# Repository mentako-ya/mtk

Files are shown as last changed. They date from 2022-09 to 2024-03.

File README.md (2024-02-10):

# mtk

homebrew keyboard with thumb operated trackball & rotary encoder.

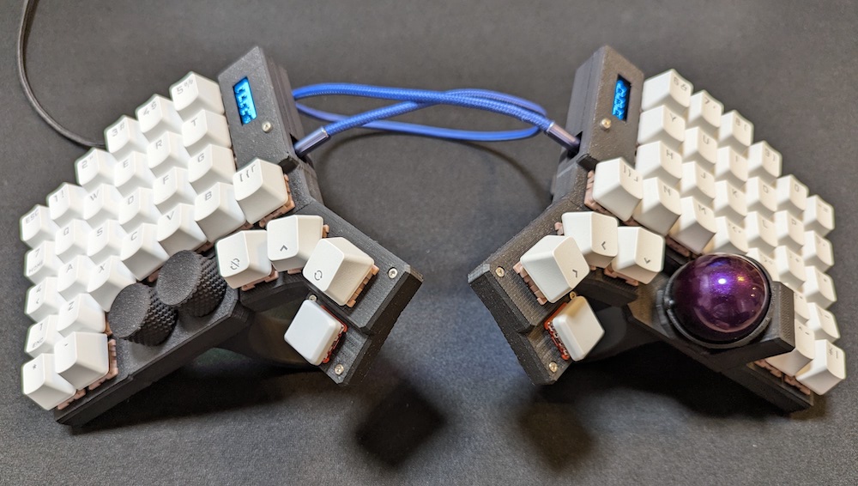
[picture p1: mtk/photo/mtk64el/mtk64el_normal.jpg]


mtk64el 作例
- キーキャップ:CORSAIR PBT DOUBLE-SHOT 交換用カラーキーキャップセット - 日本語108キー, Arctic White - CH-9911040-JP
- トラックボール：ぺリックス PERIPRO-303 GP 34 mm
- TRRSケーブル：https://shop.dailycraft.jp/products/trrs_cable_50_gloss
- USB Type-cケーブル：https://amzn.asia/d/h8pfZIJ

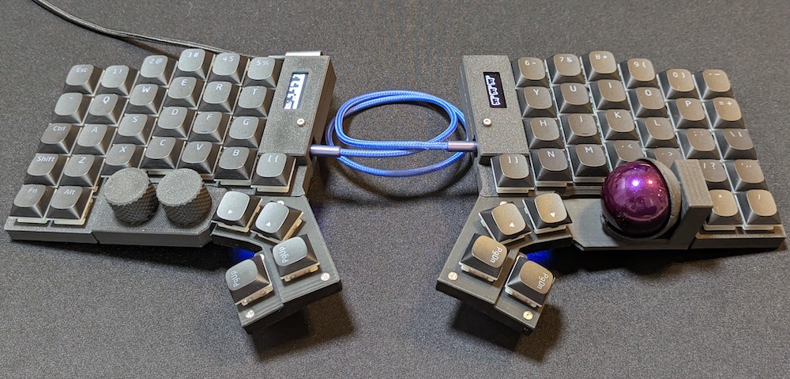
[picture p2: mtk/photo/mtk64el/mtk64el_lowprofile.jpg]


mtk64el ロープロファイル 作例



mtk64el ロープロファイル(Lofree + Chock V1) 作例
- キースイッチ(メイン部分):[LOFREE x KAILH Full POM Low Profile Switches](https://amzn.asia/d/74pwfkn)
- キーキャップ(メイン部分):[XVX ロープロファイル PBT キーキャップ](https://amzn.asia/d/7V1A6T4)
- キースイッチ(親指部分):[Kailhロープロファイルスイッチ - Pink](https://amzn.asia/d/bSlNIMm)
- キーキャップ(親指部分):[Chocfox CFX keycap](https://talpkeyboard.net/items/638b518dcc223746ee14eae8)



mtk64el Lofree Full POM ロープロファイルスイッチ取り付け例
- [LOFREE x KAILH Full POM Low Profile Switches](https://amzn.asia/d/74pwfkn)



mtk64el MX互換キースイッチ取り付け用トッププレート



mtk64el アンダーグロー

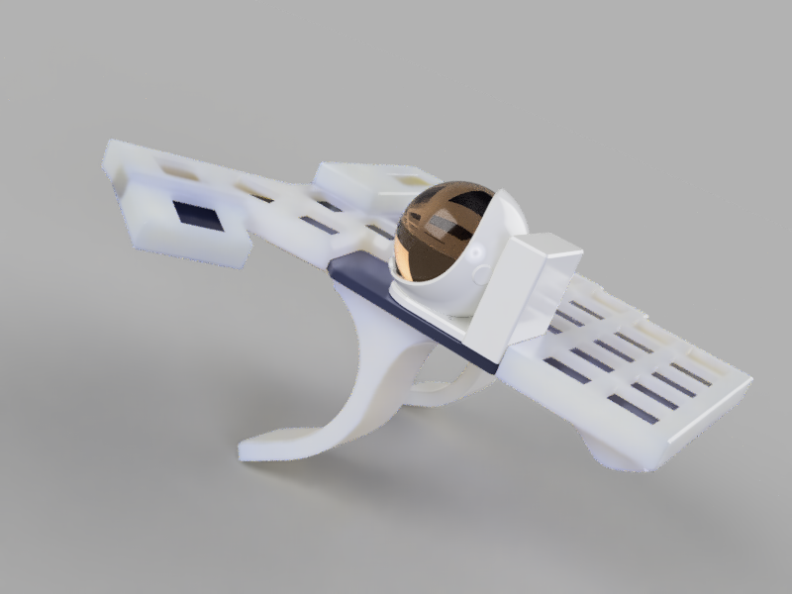
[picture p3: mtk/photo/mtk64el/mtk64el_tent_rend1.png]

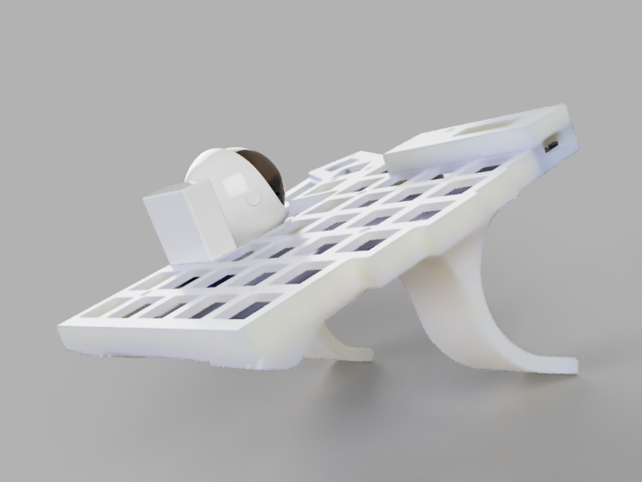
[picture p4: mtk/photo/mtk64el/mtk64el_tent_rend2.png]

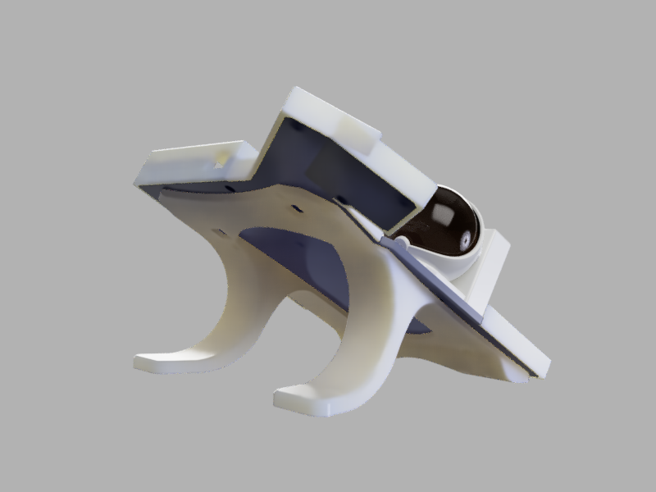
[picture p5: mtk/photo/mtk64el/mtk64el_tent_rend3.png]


[rev3ケースプリント用3Dデータ](mtk/design/mtk64elt_STL/rev3)　/ テントスタンド[3Dデータ右](mtk/design/mtk64elt_STL/rev3/mtk64el_rev3_tent_RH.stl)　/ [3Dデータ左](mtk/design/mtk64elt_STL/rev3/mtk64el_rev3_tent_LH.stl) 

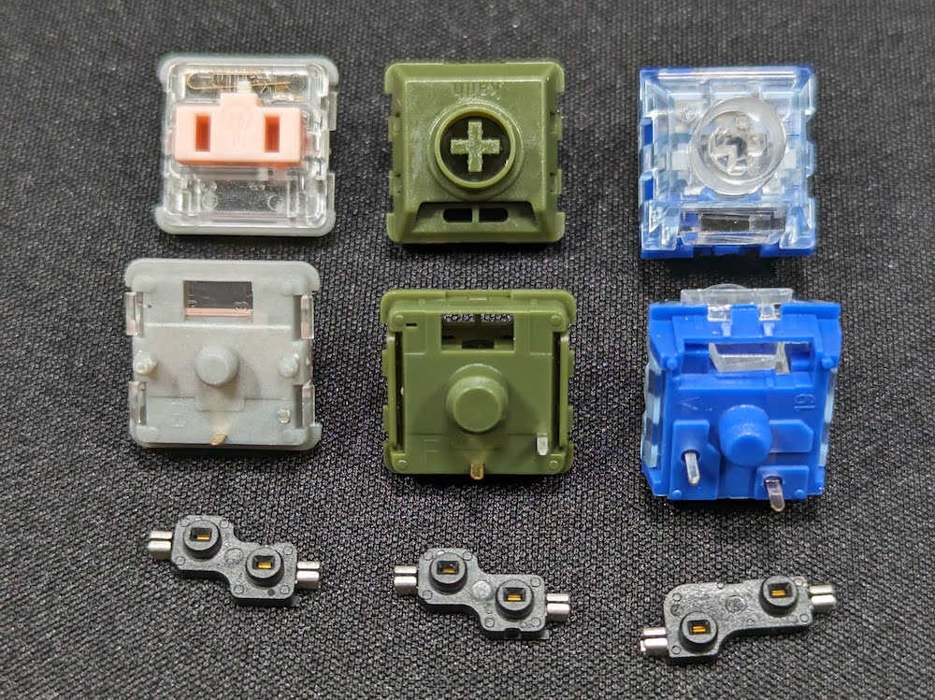
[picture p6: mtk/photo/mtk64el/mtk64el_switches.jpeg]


Chock V1スイッチ / Lofree Shadowスイッチ / MX互換スイッチ

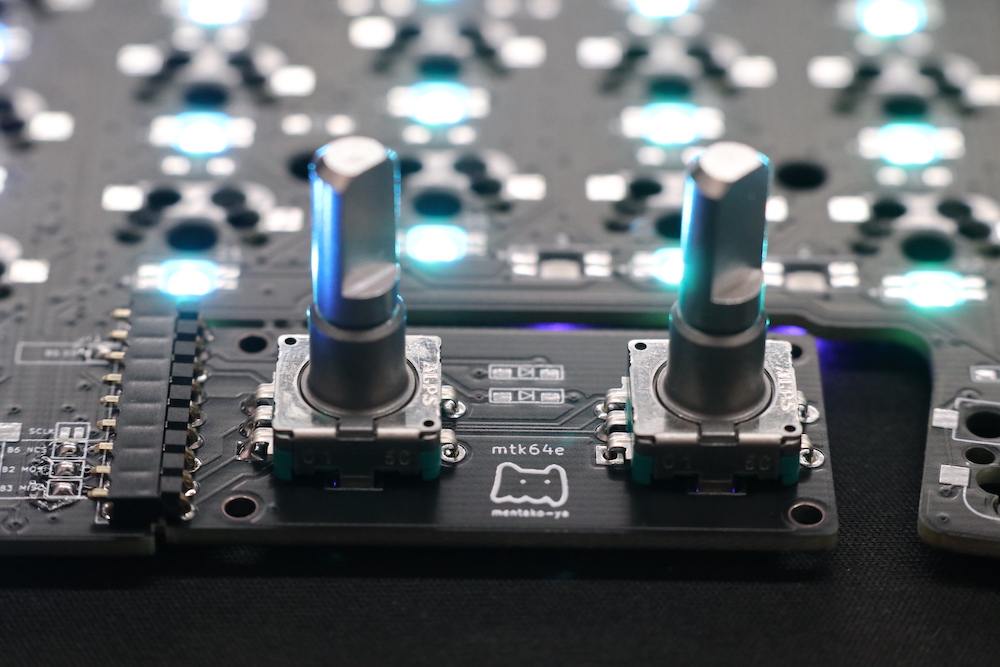
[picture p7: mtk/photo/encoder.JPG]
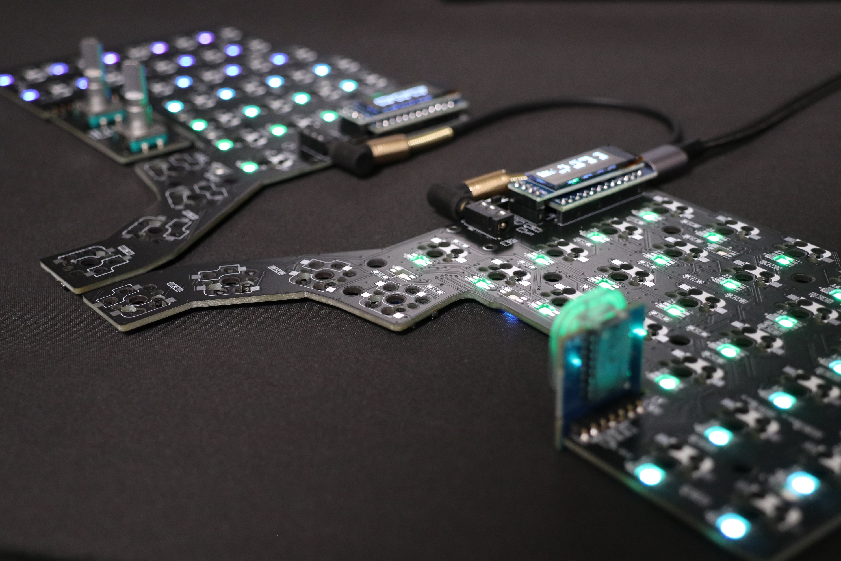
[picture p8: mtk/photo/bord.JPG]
　
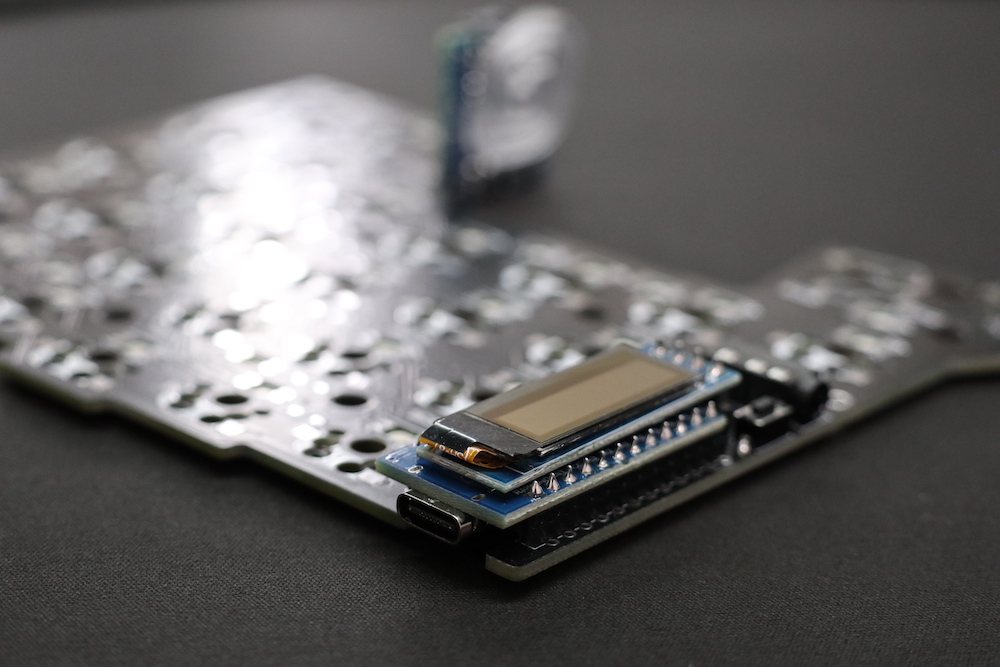
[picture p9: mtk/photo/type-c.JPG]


[insnote](https://insnote.net)様にてmtk64eのレビューを掲載いただきました。　https://insnote.net/homebrewkeyboard-mtk64e_review/

mtk64eの使用感、カスタマイズなどご紹介いただいております。導入をご検討されている方はぜひご一読ください。

## remap対応 ファームウェア  

!!! Remap https://remap-keys.app のアップデートにより、従来のファームウェア（qmk_firmware 0.16ベース）を使用したキーボードを接続すると、エラーメッセージが表示されマッピング変更ができません。
https://remap-keys.app をご利用の場合、qmk_firmware 0.22ベースのファームウェアをご使用ください。

### qmk_firmware 0.22ベース ファームウェア https://remap-keys.app をご使用ください

#### PMW3389センサー用
<details>

- [mtk_mtk64e_PMW3389_AutoMouseLayer_via.0.22.hex](https://raw.githubusercontent.com/mentako-ya/mtk/main/mtk/mtk_mtk64e_PMW3389_AutoMouseLayer_via.0.22.hex)
 rev3基板 PMW3389センサー　左ロータリーエンコーダー、右ボール用、自動マウスレイヤー切替

- [mtk_mtk64e_PMW3389_AutoMouseLayer_via_leftball.0.22.hex](https://raw.githubusercontent.com/mentako-ya/mtk/main/mtk/mtk_mtk64e_PMW3389_AutoMouseLayer_via_leftball.0.22.hex)
 rev3基板 PMW3389センサー　右ロータリーエンコーダー、左ボール用、自動マウスレイヤー切替

- [mtk_mtk64e_PMW3389_AutoMouseLayer_via_db.0.22.hex](https://raw.githubusercontent.com/mentako-ya/mtk/main/mtk/mtk_mtk64e_PMW3389_AutoMouseLayer_via_db.0.22.hex)
 rev3基板 PMW3389センサー　左右ボール用、自動マウスレイヤー切替

- [mtk_mtk64e_PMW3389_AutoMouseLayer_via_db.0.22.hex](https://raw.githubusercontent.com/mentako-ya/mtk/main/mtk/mtk_mtk64e_PMW3389_AutoMouseLayer_via_db.0.22.hex)
 rev3基板 PMW3389センサー　左右ボール用（Master側ポインター、Slabe側スクロール）、自動マウスレイヤー切替

- [mtk_mtk64e_PMW3389_AutoMouseLayer_via_db.0.22.hex](https://raw.githubusercontent.com/mentako-ya/mtk/main/mtk/mtk_mtk64e_PMW3389_AutoMouseLayer_via_db_noscrl.0.22.hex)
 rev3基板 PMW3389センサー　左右ボール用（両側ポインター）、自動マウスレイヤー切替

</details>

#### PMW3360センサー用
<details>

- [mtk_mtk64e_PMW3360_AutoMouseLayer_via.0.22.hex](https://raw.githubusercontent.com/mentako-ya/mtk/main/mtk/mtk_mtk64e_PMW3360_AutoMouseLayer_via.0.22.hex)
 rev2基板 PMW3360センサー　左ロータリーエンコーダー、右ボール用、自動マウスレイヤー切替

- [mtk_mtk64e_PMW3360_AutoMouseLayer_via_leftball.0.22.hex](https://raw.githubusercontent.com/mentako-ya/mtk/main/mtk/mtk_mtk64e_PMW3360_AutoMouseLayer_via_leftball.0.22.hex)
 rev2基板 PMW3360センサー　右ロータリーエンコーダー、左ボール用、自動マウスレイヤー切替

- [mtk_mtk64e_PMW3360_AutoMouseLayer_via_db.0.22.hex](https://raw.githubusercontent.com/mentako-ya/mtk/main/mtk/mtk_mtk64e_PMW3360_AutoMouseLayer_via_db.0.22.hex)
 rev2基板 PMW3360センサー　左右ボール用、自動マウスレイヤー切替

- [mtk_mtk64e_PMW3360_AutoMouseLayer_via_db.0.22.hex](https://raw.githubusercontent.com/mentako-ya/mtk/main/mtk/mtk_mtk64e_PMW3360_AutoMouseLayer_via_db.0.22.hex)
 rev2基板 PMW3360センサー　左右ボール用（Master側ポインター、Slabe側スクロール）、自動マウスレイヤー切替

- [mtk_mtk64e_PMW3360_AutoMouseLayer_via_db.0.22.hex](https://raw.githubusercontent.com/mentako-ya/mtk/main/mtk/mtk_mtk64e_PMW3360_AutoMouseLayer_via_db_noscrl.0.22.hex)
 rev2基板 PMW3360センサー　左右ボール用（両側ポインター）、自動マウスレイヤー切替

</details>

!!! qmk_firmware 0.16ベースのファームウェアでRemapをご使用の場合、旧バージョンのRemap https://qmk018.remap-keys.app をご利用ください。

### qmk_firmware 0.16ベース ファームウェア https://qmk018.remap-keys.app を使用
<details>

- [mtk_mtk64_via.hex](https://raw.githubusercontent.com/mentako-ya/mtk/main/mtk/mtk_mtk64_via.hex)
 rev1基板　右ボール/左ボール/左右ボール用
   
- [mtk_mtk64e_via.hex](https://raw.githubusercontent.com/mentako-ya/mtk/main/mtk/mtk_mtk64e_via.hex)
 rev2基板 PMW3360センサー　左ロータリーエンコーダー、右ボール用

- [mtk_mtk64e_left_ball_via.hex](https://raw.githubusercontent.com/mentako-ya/mtk/main/mtk/mtk_mtk64e_left_ball_via.hex)
 rev2基板 PMW3360センサー　右ロータリーエンコーダー、左ボール用
   
- [mtk_mtk64e_AutoMouseLayer_via.hex](https://raw.githubusercontent.com/mentako-ya/mtk/main/mtk/mtk_mtk64e_AutoMouseLayer_via.hex)
 rev2基板 PMW3360センサー　左ロータリーエンコーダー、右ボール用、自動マウスレイヤー切替

- [mtk_mtk64e_AutoMouseLayer_via_db.hex](https://raw.githubusercontent.com/mentako-ya/mtk/main/mtk/mtk_mtk64e_AutoMouseLayer_via_db.hex)
 rev2基板 PMW3360センサー　左右ボール用（Master側ポインター、Slabe側スクロール）、自動マウスレイヤー切替

- [mtk_mtk64e_AutoMouseLayer_via_db_noscrl.hex](https://raw.githubusercontent.com/mentako-ya/mtk/main/mtk/mtk_mtk64e_AutoMouseLayer_via_db_noscrl.hex)
 rev2基板 PMW3360センサー　左右ボール用（両側ポインター）、自動マウスレイヤー切替
   
- [mtk_mtk64e_AutoMouseLayer_via_leftball.hex](https://raw.githubusercontent.com/mentako-ya/mtk/main/mtk/mtk_mtk64e_AutoMouseLayer_via_leftball.hex)
 rev2基板　右ロータリーエンコーダー、左ボール用、自動マウスレイヤー切替

- [mtk_mtk64e_PMW3389_AutoMouseLayer_via.hex](https://raw.githubusercontent.com/mentako-ya/mtk/main/mtk/mtk_mtk64e_PMW3389_AutoMouseLayer_via.hex)
 rev3基板 PMW3389センサー　左ロータリーエンコーダー、右ボール用、自動マウスレイヤー切替

</details>

## remap用 via.json

- [mtk64_rb_via.json](https://raw.githubusercontent.com/mentako-ya/mtk/main/mtk/mtk64_rb_via.json)     rev1 mtk64　右ボール用 
    
- [mtk64_db_via.json](https://raw.githubusercontent.com/mentako-ya/mtk/main/mtk/mtk64_db_via.json)  rev1 mtk64　左右ボール用 
    
- [mtk64e_via.json](https://raw.githubusercontent.com/mentako-ya/mtk/main/mtk/mtk64e_via.json)      rev2,rev3 mtk64e　ロータリーエンコーダー＆ボール、左右ボール用

## ご自身でファームウェアをカスタマイズ、ビルドする場合 

   [via firmware ビルドガイド](qmk_firmware/keyboards/mtk/)

## 更新情報

<details>

### mtk64el rev3ケースデータを追加しました

   [rev3ケースデータ](mtk/design/mtk64elt_STL/rev3)

### mtk64el になりました
   親指末端のキーを手前斜め下、親指側面で押下する位置に配置しました。

   親指部分にCherryMX互換キーを使用する場合でも、末端のキーのみロープロファイルで使用する設計です。
   
   全キーロープロファイル化が可能になりました。
  
   ロープロファイルキーはGateron Low Profile 2.0 (KS-33) を使用します。（Kailh chock v1は使用できません）

   トラックボールケースの形状を変更してボールが落ちにくくなりました。
   
   LEDはアンダーグローのみになりました。

   ファームウェアはmtk64eと共通です。

### ファームウェアが　qmk_firmware 0.22 ベースになりました
   ファームウェアを　qmk_firmware 0.22 ベースに更新しました。
   
   Remap [https://remap-keys.app] のアップデートに対応しました。

### トラックボールセンサーをPMW3389に更新しました
   トラックボールセンサーをより高性能なPMW3389DM-T3QUに更新しました。
   
   [PMW3360DM-T2QUとPMW3389DM-T3QUの比較](https://www.pixart.com/products-comparison/7/Optical_Mouse_Sensor)
   
   ファームウェアはPMW3389センサー用になります。
   
   従来のPMW3360センサーを使用したキーボードをご使用の場合、ファームウェアはPMW3360センサー用をご使用ください。
   
### 右ロータリーエンコーダー、左ボール用、自動マウスレイヤー切替有効　ファームウェアを追加しました

   [mtk_mtk64e_AutoMouseLayer_via_leftball.hex](https://raw.githubusercontent.com/mentako-ya/mtk/main/mtk/mtk_mtk64e_AutoMouseLayer_via_leftball.hex) rev2基板用　右ロータリーエンコーダー、左ボール用、自動マウスレイヤー切替

   ソースコード : https://github.com/mentako-ya/mtk/tree/mtk64e_leftball

### ファームウェアを再ビルドしました
   [mtk_mtk64e_AutoMouseLayer_via.hex](https://raw.githubusercontent.com/mentako-ya/mtk/main/mtk/mtk_mtk64e_AutoMouseLayer_via.hex) rev2基板用　左ロータリーエンコーダー、右ボール用、自動マウスレイヤー切替

   [mtk_mtk64e_AutoMouseLayer_via_db.hex](https://raw.githubusercontent.com/mentako-ya/mtk/main/mtk/mtk_mtk64e_AutoMouseLayer_via_db.hex) rev2基板用　左右ボール用（Master側ポインター、Slabe側スクロール）、自動マウスレイヤー切替

   [mtk_mtk64e_AutoMouseLayer_via_db_noscrl.hex](https://raw.githubusercontent.com/mentako-ya/mtk/main/mtk/mtk_mtk64e_AutoMouseLayer_via_db_noscrl.hex) rev2基板用　左右ボール用（両側ポインター）、自動マウスレイヤー切替
   
   qmk_firmwareのバージョン不整合により、キーボード接続時に初期化処理が正しく動作しない場合があったため、qmk_firmware 0.16.3 で再ビルドしました。
   再ビルドによりレイヤー３のカスタムキーコードが変わりました。ファームウェア更新した場合、キーマップをリセットするか、新しいキーコードとの対応を確認してキーマッピングを修正してください。
　
### オーディオ制御とシステム制御キーを有効化しました
   [mtk_mtk64e_AutoMouseLayer_via.hex](https://raw.githubusercontent.com/mentako-ya/mtk/main/mtk/mtk_mtk64e_AutoMouseLayer_via.hex)
   
   ご自身でファームウェアをビルドする場合、[rules.mk](https://github.com/mentako-ya/mtk/blob/cd9f4ba413dade68378f4804782a1528e7ef739e/qmk_firmware/keyboards/mtk/mtk64e/rules.mk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)の
   ```EXTRAKEY_ENABLE = no        # Audio control and System control```
   をyesに修正してください。
   
   ファームウェアのサイズが上限に近いため、有効化している機能の組み合わせによっては、ファイル容量オーバーによりビルドできない場合があります。

### 左右ボール用ファームウェアを追加しました。
   [mtk_mtk64e_AutoMouseLayer_via_db.hex](https://raw.githubusercontent.com/mentako-ya/mtk/main/mtk/mtk_mtk64e_AutoMouseLayer_via_db.hex) rev2基板用　左右ボール用（Master側ポインター、Slabe側スクロール）、自動マウスレイヤー切替
   [mtk_mtk64e_AutoMouseLayer_via_db_noscrl.hex](https://raw.githubusercontent.com/mentako-ya/mtk/main/mtk/mtk_mtk64e_AutoMouseLayer_via_db_noscrl.hex) rev2基板用　左右ボール用（両側ポインター）、自動マウスレイヤー切替

### 意図せずマウスレイヤー２が解除されてしまうバグに対応しました。
自動でマウスレイヤーに切り替わっている間に手動でレイヤー２に切り替えると、一定時間経過後にレイヤー２が解除されるバグに対応しました。

### エンコーダーの解像度を調整しました。
[エンコーダーの仕様](https://tech.alpsalpine.com/j/products/detail/EC11E18244AU/#ancFig3)に合わせて、'ENCODER_RESOLUTION 4 → 2' に調整しました。

### 自動マウスレイヤーから元のレイヤーに戻る時間を0.1秒単位で調整可能にしました。
調整用カスタムキーコード
- KC_TO_RESET_INC　0x5DB2
- KC_TO_RESET_DEC　0x5DB3

### トラックボール操作時に自動でマウスレイヤー2に切り替わる対応を追加しました。
[takashicompanyさんの実装](https://zenn.dev/takashicompany/articles/69b87160cda4b9)を参考にしています。

[mtk_mtk64e_AutoMouseLayer_via.hex](https://raw.githubusercontent.com/mentako-ya/mtk/main/mtk/mtk_mtk64e_AutoMouseLayer_via.hex)

※容量の都合でこちらのファームウェアはLEDエフェクトを省略しています。（LEDのOn/Off、色と明るさ調整は可能、点滅やグラデーションは不可）
LEDエフェクトが必要な場合、従来のファームウェアをご利用ください。

### 通電直後のエンコーダー誤作動対応を追加しました。

### バックプレートが透明アクリル製になりました。
バックプレート固定用の低頭6角穴付きボルトの付け外しには[T5サイズのレンチ](https://amzn.asia/d/b8Xeegc)を使用します。

### メインの基板が黒色になりました。

### 親指のロープロファイルキーの向きを内向きに変更しました。
[MCC-profile POM Choc keycap](https://shop.yushakobo.jp/products/3694)のような、シリンドリカル（円柱状に凹んでいる形状）のキーを使用できます。

[MBK Choc Low-Profile Keycaps](https://shop.yushakobo.jp/products/mbk-choc-low-profile-keycaps)のような、スフィリカル（お椀状に凹んでいる形状）のキーでは手前側の角が親指に当たって痛くなってしまう方におすすめです。（mtk64elでは使用できません）
</details>

## キーボードの接続

まず、動作確認のために右左の各キーボードを単体でPCに接続し、キー入力が可能であること、OLEDにキーボードの情報が表示されることを確認してください。（OLEDは一定時間操作しないと消灯します）

USB Type-c ケーブルは充電器や携帯電話などの製品に付属のケーブルは使用できません。USB2.0/USB3.0の表記のあるデータ通信用のケーブルを使用してください。
PCからキーボードとして認識されない場合、USBケーブルがデータ通信用ではない、USBケーブルがケースと干渉してプロマイクロにしっかり刺さっていないなどの可能性があります。

根元の形状が太いUSBケーブルや特殊な形状のUSBケーブルは、ケースと干渉する場合があります。
作例は[こちら](https://amzn.asia/d/gQuaIi1)のUSBケーブルを使用しています。

USB2.0のケーブルを使用してType-c端子にケーブルをきちんと差し込んだたうえで、接続時にキー入力できない場合やOLEDに何も表示されない場合、ロゴが表示されていてキー情報（数値やコード）が表示されない場合は、OLEDの斜め下にあるリセットボタン（ボルトの頭）をプッシュするか、キーボードを接続し直してください。

USBケーブルに問題がなく、動作しない場合は、プロマイクロのコンスルーが抜けかけている、回路がショートしていて起動できない（LEDの取り付け方向間違いでこの状態になることが多いです）などのハードウェアの問題か、ファームウェアが消えているなどのソフトウェアの問題が考えられます。

USB接続時にプロマイクロ裏側の赤いランプが点灯しているか、USB端子の隙間から確認してください。
赤いLEDが点灯していない場合、点灯してもすぐ消えてしまう場合ば、ハードウェアの問題です。

左右単体で動作確認できたら、TRSケーブルで左右を接続し、どちらか一方のUSB端子をPCに接続してください。

左右を繋ぐと動作しない場合、TRSケーブルが奥まできちんと刺さっていないか、TRSケーブルの断線、接触不良が考えられます。
TRSケーブルは、ケーブル付け根が本体のケースの中まで入り込む設計です。ねじ込むようにしてしっかり奥まで差し込んでください。

ジャックの付け根が太いケーブルやL字のケーブルはケースに干渉するため、根元の細いケーブルを使用するか、ケース側を加工する必要があります。
作例は[こちら](https://shop.dailycraft.jp/products/trrs_cable_50_gloss)のTRRSケーブルを使用しています。

スリープからの復帰の際にキーボードが動作しなくなる場合、PC側のUSB省電力設定やUSBセレクティブサスペンドをOFFにするか、OLED斜め下のリセットボタン押下、USBケーブルの再接続で復帰してください。

## キーマップ変更

キーマップの変更はChromeブラウザを使用して、https://remap-keys.app　で変更します。

（旧バージョンのqmk_firmware 0.16ベースのファームウエアをご使用の場合、https://qmk018.remap-keys.app　で変更します。）

下記に本キーボードを使用する際に最低限必要な手順を記載します。

remapの一般的な使用方法はサリチル酸さんの記事などをご参照ください。

　https://salicylic-acid3.hatenablog.com/entry/remap-manual

1. [START REMAP FOR YOUR KEYBORD]　をクリック

<img width="500" src="mtk/remap_img/remap_1.png">

2. [+ KEYBORD]をクリック

<img width="500" src="mtk/remap_img/remap_2.png">

3. [mtk64] か。[mtk64e]を選択して接続.

<img width="250" src="mtk/remap_img/remap_3.png">

4. Jsonファイルのアップロードを求められるので、下記からレイアウトに合わせたjsonファイルをダウンロードして使用する

<img width="500" src="mtk/remap_img/remap_4.png">

- mtk64 右ボール用 [mtk64_rb_via.json](https://raw.githubusercontent.com/mentako-ya/mtk/main/mtk/mtk64_rb_via.json)
- mtk64 左右ボール用 [mtk64_db_via.json](https://raw.githubusercontent.com/mentako-ya/mtk/main/mtk/mtk64_db_via.json)
- mtk64e ロータリーエンコーダー＆ボール、両側ボール用 [mtk64e_via.json](https://raw.githubusercontent.com/mentako-ya/mtk/main/mtk/mtk64e_via.json)

5. キーマップの変更 / キーマップの書き込み（右上Flashボタン） /　変更したキーマップの保存　/　キーマップのPDFダウンロード　などが可能

右ボール　キーマップサンプル

- via keyleyout(right ball) [mtk64_rb_via.json](https://raw.githubusercontent.com/mentako-ya/mtk/main/mtk/mtk64_rb_via.json)
- sample keymap cheetsheet(right ball) [mtk64_rb_keymap_cheatsheet.pdf](mtk/mtk64_rb_keymap_cheatsheet.pdf)

<img width="1186" alt="remap_key_leyout" src="mtk/remap_img/mtk64_rb_keymap.png">

左右ボール　キーマップサンプル

- via keyleyout(double ball) [mtk64_db_via.json](https://raw.githubusercontent.com/mentako-ya/mtk/main/mtk/mtk64_db_via.json)
- sample keymap cheetsheet(double ball) [mtk64_db_keymap_cheatsheet.pdf](mtk/mtk64_db_keymap_cheatsheet.pdf)

<img width="1186" alt="remap_key_leyout_double_ball" src="mtk/remap_img/mtk64_db_keymap.png">

mtk64e ロータリーエンコーダー＆ボール、左右ボール　キーマップサンプル

- via keyleyout(rotary encoder) [mtk64e_via.json](https://raw.githubusercontent.com/mentako-ya/mtk/main/mtk/mtk64e_via.json)
- sample keymap cheetsheet(rotary encoder) [mtk64e_keymap_cheatsheet.pdf](mtk/mtk64e_keymap_cheatsheet.pdf)
- sample keymap cheetsheet(rotary encoder) [mtk64e_AutoMouseLayer_keymap_cheatsheet.pdf](mtk/mtk64e_AutoMouseLayer_keymap_cheatsheet.pdf)

<img width="1186" alt="remap_key_leyout_rotary_encoder" src="mtk/remap_img/mtk64e_keymap.png">

※ 製品出荷時点でキーボードに設定済みのマッピングは、ファームウェアのデフォルトキーマッピングとは一部異なる場合があります。

キーマップのリセットや、キーボードの初期化を行うと、キーマップはファームウェアのデフォルトキーマップにリセットされます。

キーマップ変更やリセットを行う前に、初期のマッピングの状態でマップの保存をお勧めします。

## ファームウェア更新
[Pro Micro Web Updater](https://sekigon-gonnoc.github.io/promicro-web-updater/index.html) を使用してファームウェアを更新できます。

出荷時に書き込まれているファームウェアは[mtk_mtk64e_AutoMouseLayer_via.hex](https://raw.githubusercontent.com/mentako-ya/mtk/main/mtk/mtk_mtk64e_AutoMouseLayer_via.hex)になります。　

[Pro Micro Web Updater](https://sekigon-gonnoc.github.io/promicro-web-updater/index.html) にアクセスし、事前にダウンロードしたファームウェアをアップロードします。

キーボードの左右どちらか一方をUSB接続し、画面上の[flash]ボタンを押下します。

シリアルポートへの接続要求のウインドウが表示されるので、OLED斜め下のリセットスイッチ（ボルトの頭）を２回連続でクリックします。

シリアルポートの一覧に「Pro Micro 5v」が表示されるので、選択して接続ボタンを押下します。

## 基本的な使用方法

本キーボードは、レイヤー０〜3の４種類のキーマップを切り替えて使用します。

レイヤーの切り替えは左手親指キーのHOLD（シフトキーのように押したままにすること）に割り当てられており、左端からLayer(1),Layer(2),Layer(3)が設定されています。

- レイヤー０:通常のアルファベット入力
- レイヤー１:Shiftキー押下相当（大文字入力や記号入力）
- レイヤー２:右手のキーがマウスのボタンに切り替わる
- レイヤー３:トラックボールがスクロールモードに切り替わる、キースイッチはLEDの調整、トラックボールの速度、スクロールの速度調整

自動マウスレイヤー切替に対応したファームウェアでは、トラックボールを一定距離動かすと自動的にレイヤー2に切り替わり、マウスボタンクリックが可能になります。
デフォルトでは１秒間何も操作しないとレイヤー0に戻ります。
自動マウスレイヤー切替機能がOnの場合、OLED３行目が反転表示されます。
（レイヤー３左側のキーボード最下段左から２番目のキーで自動切替機能On／Off）

## レイヤー３トラックボール設定のコード値
レイヤー３にマッピングされているキーのうち、トラックボールの設定を行うキーは、のカスタムコードで設定します。
Remapでは User0 ~（旧バージョンRemapでは16進数）で設定します。

コード値については下記の表を参照してください。

- RemapのUserキー:旧バージョンRemapの16進コード:keymap.cのカスタムコード　

### レイヤー３トラックボール設定のコード値　mtk64　（mtk_mtk64_via.hex/mtk_mtk64e_via.hex）
- User 0:0x5DA5:KBC_RST    トラックボール設定リセット
- User 1:0x5DA6:KBC_SAVE   トラックボール設定保存（次回接続時にトラックボール設定が保存された値になっている）
- User 2:0x5DA7:CPI_I100   トラックボールのカーソル速度 +100
- User 3:0x5DA8:CPI_D100   トラックボールのカーソル速度 -100
- User 4:0x5DA9:CPI_I1K    トラックボールのカーソル速度  +1000
- User 5:0x5DAA:CPI_D1K    トラックボールのカーソル速度 -1000
- User 6:0x5DAB:SCRL_TO    トラックボールのスクロールモードOn/Off
- User 7:0x5DAC:SCRL_MO    トラックボールのスクロールモードOn
- User 8:0x5DAD:SCRL_DVI   トラックボールのスクロール速度を下げる
- User 9:0x5DAE:SCRL_DVD   トラックボールのスクロール速度を上げる

### レイヤー３トラックボール設定のコード値　mtk64e自動マウスレイヤー　（mtk_mtk64e_AutoMouseLayer_via.0.22.hex）
- User 0:0x5DB1:KBC_RST    トラックボール設定リセット
- User 1:0x5DB2:KBC_SAVE   トラックボール設定保存（次回接続時にトラックボール設定が保存された値になっている）
- User 2:0x5DB3:CPI_I100   トラックボールのカーソル速度 +100
- User 3:0x5DB4:CPI_D100   トラックボールのカーソル速度 -100
- User 4:0x5DB5:CPI_I1K    トラックボールのカーソル速度 +1000
- User 5:0x5DB6:CPI_D1K    トラックボールのカーソル速度 -1000
- User 6:0x5DB7:SCRL_TO    トラックボールのスクロールモードOn/Off
- User 7:0x5DB8:SCRL_MO    トラックボールのスクロールモードOn
- User 8:0x5DB9:SCRL_DVI   トラックボールのスクロール速度を下げる
- User 9:0x5DBA:SCRL_DVD   トラックボールのスクロール速度を上げる

### レイヤー３自動マウスレイヤー切替設定のコード値　mtk64e自動マウスレイヤー　（mtk_mtk64e_AutoMouseLayer_via.0.22.hex）
- User10:0x5DBB:KC_TG_CLICKABLE     自動マウスレイヤー切替On/Off (有効時にOLEDを反転表示）
- User11:0x5DBC:KC_TO_CLICKABLE_INC 自動マウスレイヤー切替距離 +
- User12:0x5DBD:KC_TO_CLICKABLE_DEC 自動マウスレイヤー切替距離 -
- User13:0x5DBE:KC_TO_RESET_INC     自動マウスレイヤーから元のレイヤーに戻る時間 + 0.1秒
- User14:0x5DBF:KC_TO_RESET_DEC.    自動マウスレイヤーから元のレイヤーに戻る時間 - 0.1秒
 
## 左右トラックボール構成の動作

[mtk_mtk64e_AutoMouseLayer_via_db.hex](https://raw.githubusercontent.com/mentako-ya/mtk/main/mtk/mtk_mtk64e_AutoMouseLayer_via_db.hex) を使用するとUSBケーブルを挿した側（Master)がポインター操作、反対側（Slave）がスクロール操作（上下左右）になります。
レイヤー３に切り替えた際に左右のモードが入れ替わります。

[mtk_mtk64e_AutoMouseLayer_via_db_noscrl.hex](https://raw.githubusercontent.com/mentako-ya/mtk/main/mtk/mtk_mtk64e_AutoMouseLayer_via_db_noscrl.hex) を使用するとMaster側Slave側ともポインター操作になります。
レイヤー３に切り替えた際に左右ともスクロールになります。

## トラックボールのお手入れ
ボールとボールケースの白い支持球はこまめに掃除していただくと、滑りがよくなり快適に使用できます。

白い支持球周辺に埃が溜まりますので、時々ボールを外してメガネ拭きなどで掃除してください。
ボールの滑りが悪いと、狙ったところをカーソルが飛び越してしまい、使いづらくなります。

ボールに[シリコンスプレー](https://amzn.asia/d/2fwdtvX)を少量塗布して、ティッシュ、メガネ拭き、[キムワイプ](https://www.amazon.co.jp/dp/B001EHI9XI)などで軽く拭っていただくと、滑りが良くなり、操作性が向上します。

定期的にシリコンを塗布する必要がありますが、シリコンスプレーは1本あれば数年使用できます。

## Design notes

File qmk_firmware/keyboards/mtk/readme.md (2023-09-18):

## How to build

1. [mtk](https://github.com/mentako-ya/mtk/)をチェックアウトします.

    ※ チェックアウト先 `~/git` は適宜変更

    ```console
    $ cd ~/git
    $ git clone https://github.com/mentako-ya/mtk.git mtk
    ```

2. [qmk/qmk_firmware](https://github.com/qmk/qmk_firmware/) より qmk_firmware ver.0.22.3 をチェックアウトします.

    ```console
    $ cd ~/git
    $ git clone https://github.com/qmk/qmk_firmware.git --depth 1 --recurse-submodules --shallow-submodules -b 0.22.3 qmk_firmware
    ```

3. `qmk_firmware/keyboards/` フォルダに　`/mtk/qmk_firmware/keyboards/mtk` のシンボリックリンクを作成し、`qmk_firmware/keyboards/mtk` とします。

    ```console
    $ ls
    mtk/ qmk_firmware/

    $ cd qmk_firmware/keyboards
    $ ln -s ../../mtk/qmk_firmware/keyboards/mtk mtk
    $ ls mtk/
    drivers/  mtk/  lib/  readme.md
    ```

4. ファームウェアをビルドしてし、キーボードに書き込み(flash)します.

   - 右ボール左エンコーダーの場合
   
        [qmk_firmware/keyboards/mtk/mtk64e/keymaps/via/config.h](qmk_firmware/keyboards/mtk/mtk64e/keymaps/via/config.h) を確認します。
        ```c++
        // #### 自動マウスレイヤー切替有効化 ####
        #define AUTO_MOUSE_LAYER_ENABLE

        // #### エンコーダー設定 ####
        // 左エンコーダー有効 左ボール無効（デフォルト）
        #define ENCODER_LEFT_ENABLE
        // 右エンコーダー有効 右ボール無効
        //#define ENCODER_RIGHT_ENABEL

        // #### 両側ボール設定 ####
        //#undef ENCODER_ENABLE
        // slave側トラックボールをスクロール操作に使用する場合（デフォルト）
        //#define SLAVE_SCRL_DISABLE 0
        // slave側トラックボールをポインター操作に使用する場合
        //#define SLAVE_SCRL_DISABLE 1
        ```

     - make を使用する場合.
        ```console
        $ cd ~/git/qmk_firmware
        $ make -j8 SKIP_GIT=yes mtk/mtk64e:via:flash
        ```

     - qmk を使用する場合.　　　
        ```console
        $ cd ~/git/qmk_firmware
        $ qmk clean -a
        $ qmk flash -kb mtk/mtk64e -km via
        Ψ Compiling keymap with gmake --jobs=1 mtk/mtk64e:via:flash
        ~
        Waiting for USB serial port - reset your controller now (Ctrl+C to cancel)..........
        ```
        ビルドが成功するとUSBシリアルポートの接続待ちになるので、接続したキーボードのリセットスッチを２回押下して書き込みを開始します。
        一方の書き込みが完了したら、再度flashを実行して反対のキーボードにも書き込みます。

   - 左ボール右エンコーダーの場合
   
        [qmk_firmware/keyboards/mtk/mtk64e/keymaps/via/config.h](qmk_firmware/keyboards/mtk/mtk64e/keymaps/via/config.h) を編集します。
        ```c++
        // #### 自動マウスレイヤー切替有効化 ####
        #define AUTO_MOUSE_LAYER_ENABLE

        // #### エンコーダー設定 ####
        // 左エンコーダー有効 左ボール無効（デフォルト）
        //#define ENCODER_LEFT_ENABLE
        // 右エンコーダー有効 右ボール無効
        #define ENCODER_RIGHT_ENABEL

        // #### 両側ボール設定 ####
        // #undef ENCODER_ENABLE
        // slave側トラックボールをスクロール操作に使用する場合（デフォルト）
        // #define SLAVE_SCRL_DISABLE 0
        // slave側トラックボールをポインター操作に使用する場合
        //#define SLAVE_SCRL_DISABLE 1
        ```
        右ボール左エンコーダーの場合と同じくビルドしてし、キーボードに書き込み(flash)します。
    
   - 両側ボールの場合
   
        [qmk_firmware/keyboards/mtk/mtk64e/keymaps/via/config.h](qmk_firmware/keyboards/mtk/mtk64e/keymaps/via/config.h) を編集します。
        ```c++
        // #### 自動マウスレイヤー切替有効化 ####
        #define AUTO_MOUSE_LAYER_ENABLE

        // #### エンコーダー設定 ####
        // 左エンコーダー有効 左ボール無効（デフォルト）
        #define ENCODER_LEFT_ENABLE
        // 右エンコーダー有効 右ボール無効
        //#define ENCODER_RIGHT_ENABEL

        // #### 両側ボール設定 ####
        #undef ENCODER_ENABLE
        // slave側トラックボールをスクロール操作に使用する場合（デフォルト）
        #define SLAVE_SCRL_DISABLE 0
        // slave側トラックボールをポインター操作に使用する場合
        //#define SLAVE_SCRL_DISABLE 1
        ```
        右ボール左エンコーダーの場合と同じくビルドしてし、キーボードに書き込み(flash)します。

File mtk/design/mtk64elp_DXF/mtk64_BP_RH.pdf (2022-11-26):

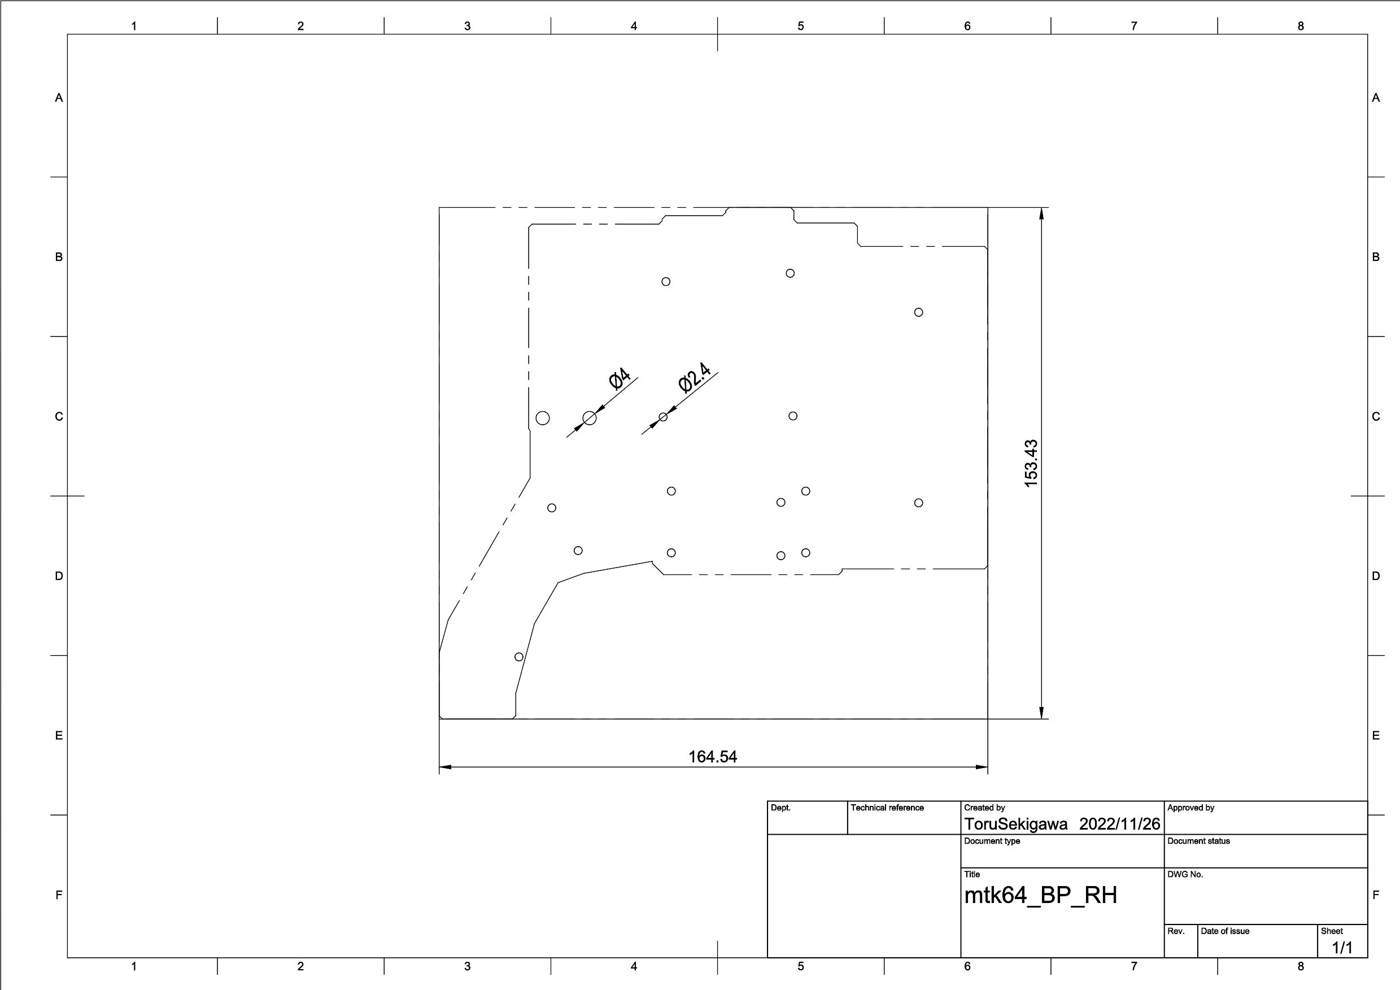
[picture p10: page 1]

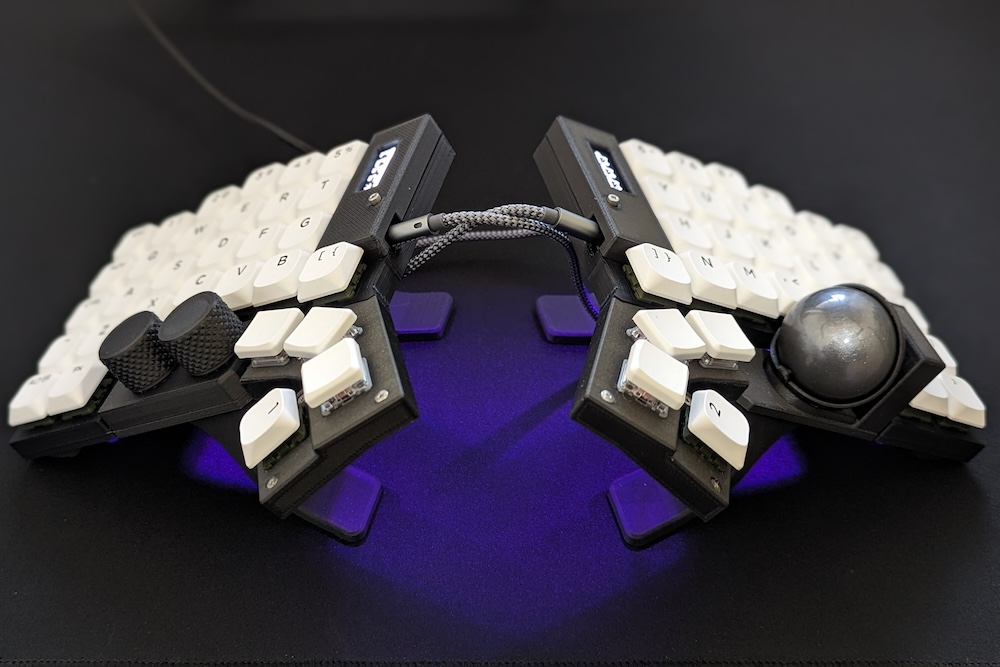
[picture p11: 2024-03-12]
mtk/photo/mtk64el/mtk64el_low_tent.jpg

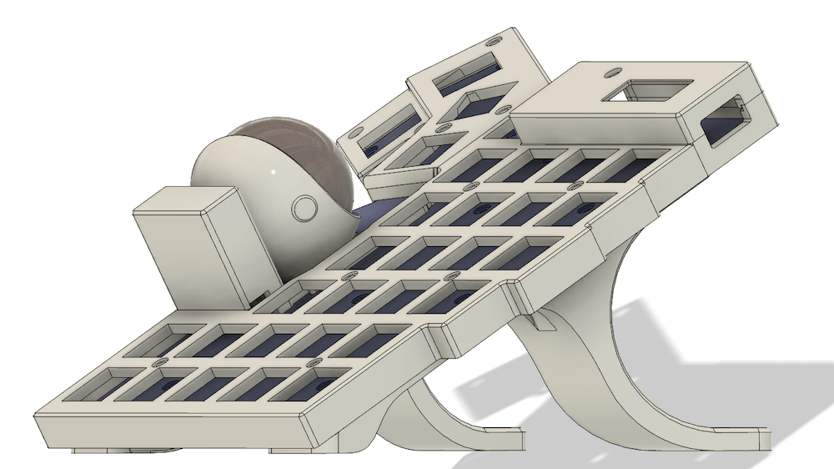
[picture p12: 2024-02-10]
mtk/photo/mtk64el/mtk64el_lowpro_case.png

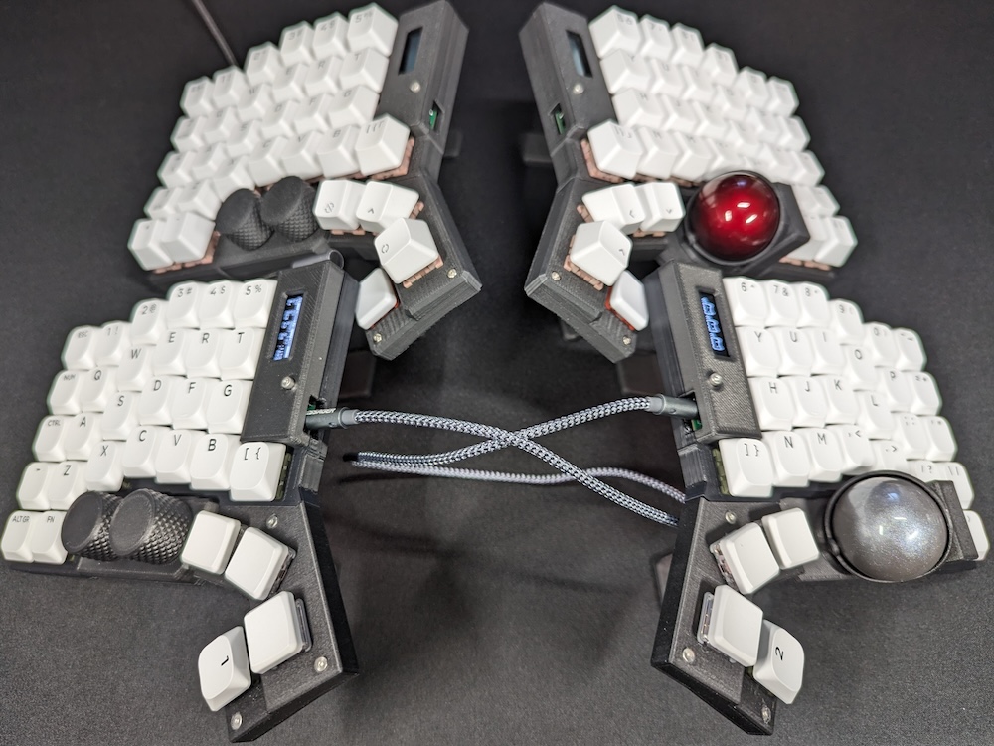
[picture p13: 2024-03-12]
mtk/photo/mtk64el/mtk64el_low_high.jpg

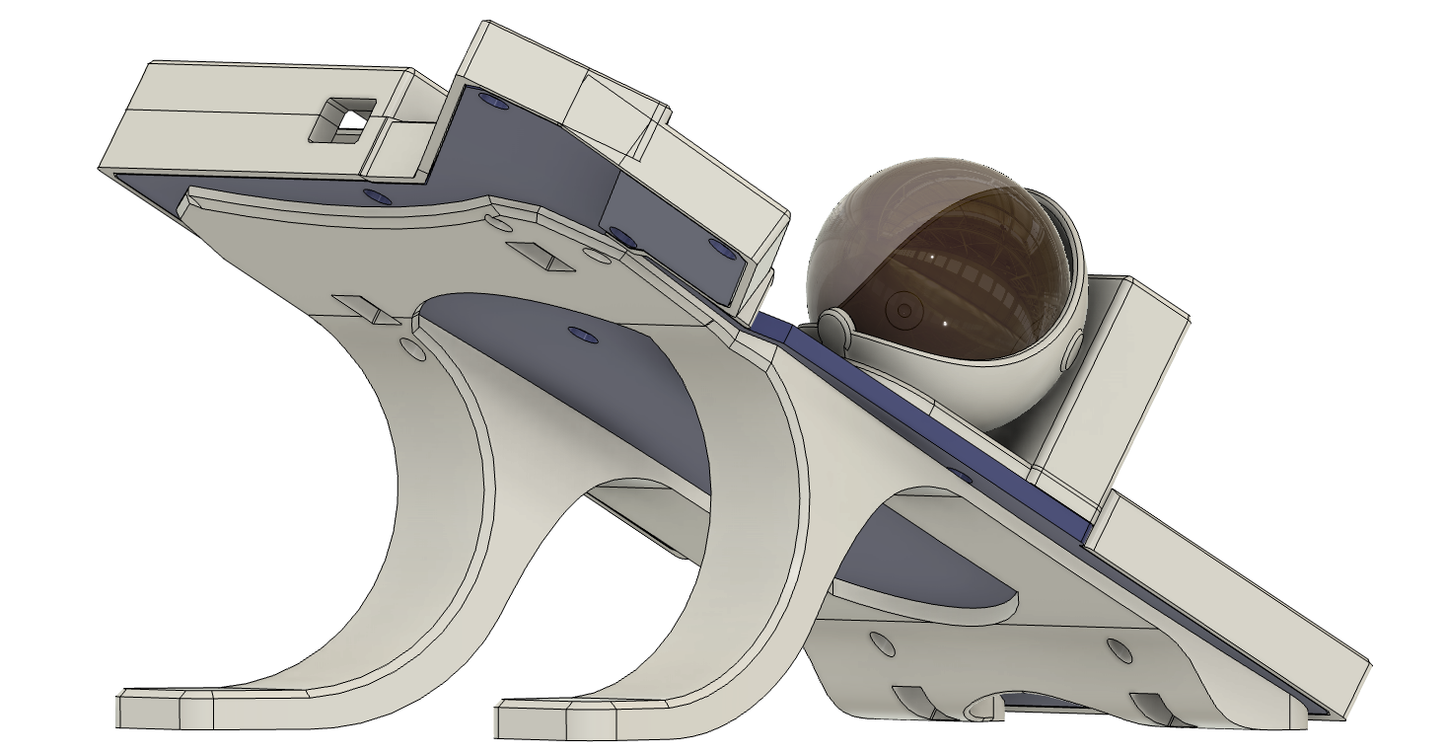
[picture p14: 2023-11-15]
mtk/photo/mtk64el/mtk64el_tent.png

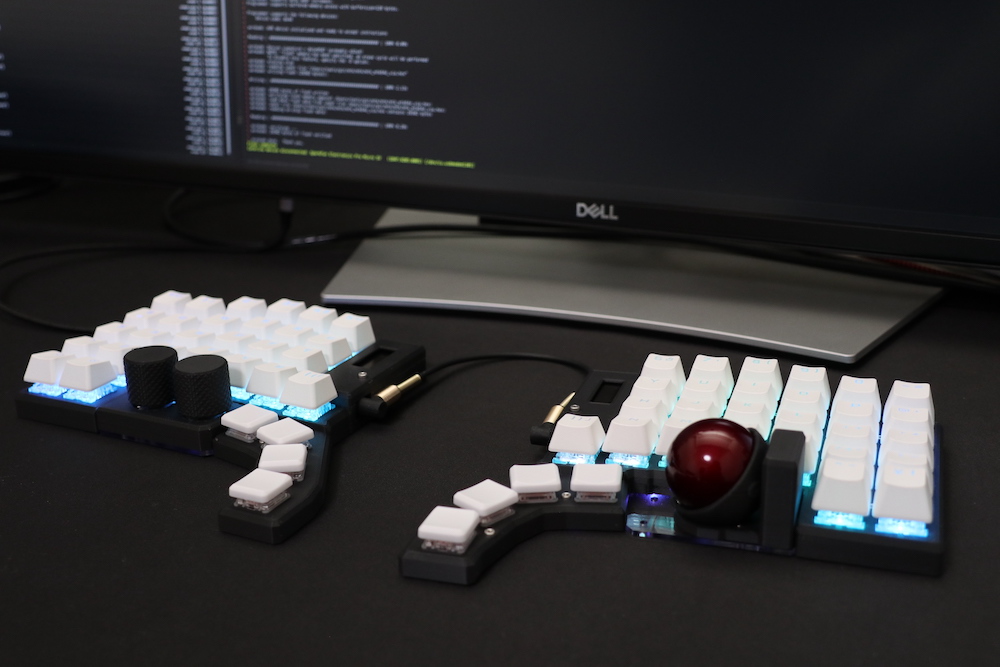
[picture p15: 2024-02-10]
mtk/photo/mtk64e.JPG

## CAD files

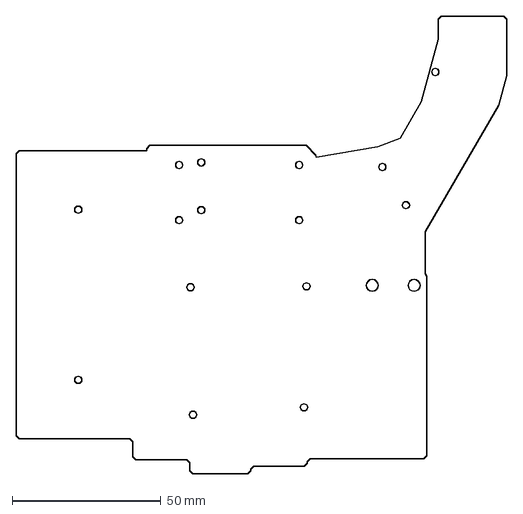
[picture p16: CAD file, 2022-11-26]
mtk/design/mtk64elp_DXF/mtk64_BP_RH.dxf
164.5 x 153.4 mm

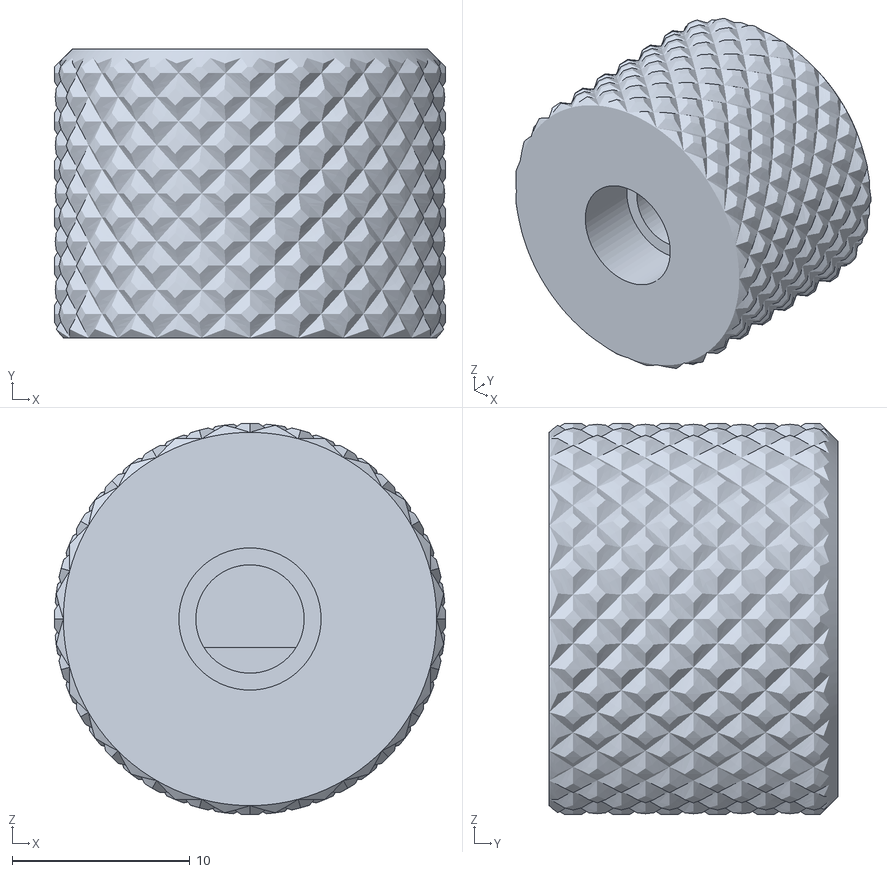
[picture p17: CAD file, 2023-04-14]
mtk/design/mtk64elp_STL/EC11N1524402_knob_v7.stl
22.0 x 16.2 x 22.0

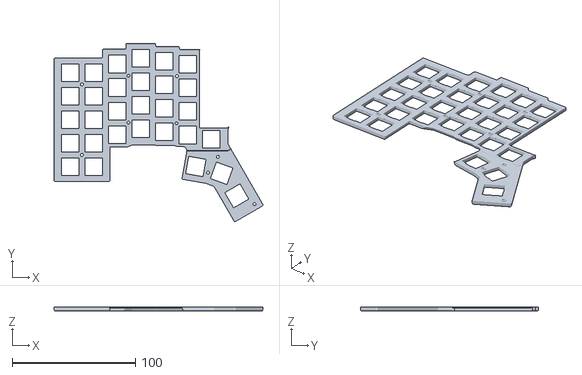
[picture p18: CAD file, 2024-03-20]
mtk/design/mtk64elt_STL/rev3/mtk64el_rev3_top_RH.stl
169.3 x 144.3 x 2.90

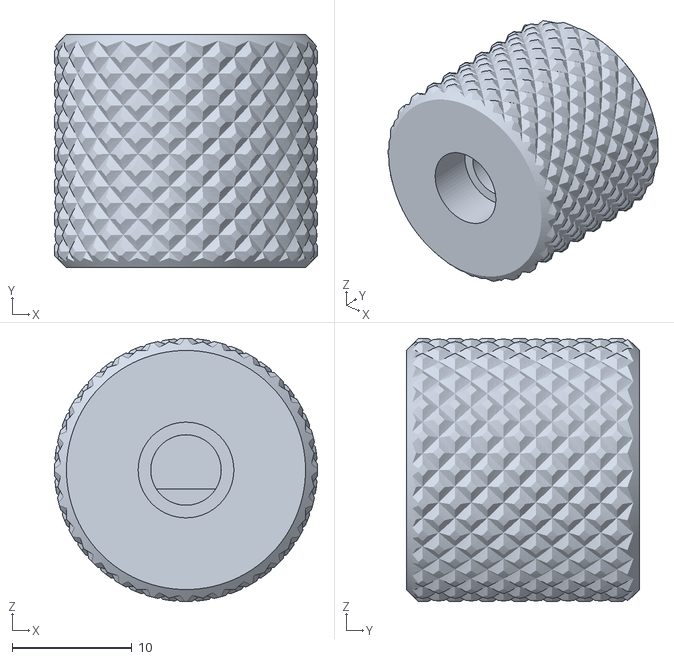
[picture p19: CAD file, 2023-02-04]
mtk/design/mtk64elp_STL/EC11E18244AU_Knob v8.stl
22.0 x 19.5 x 22.0

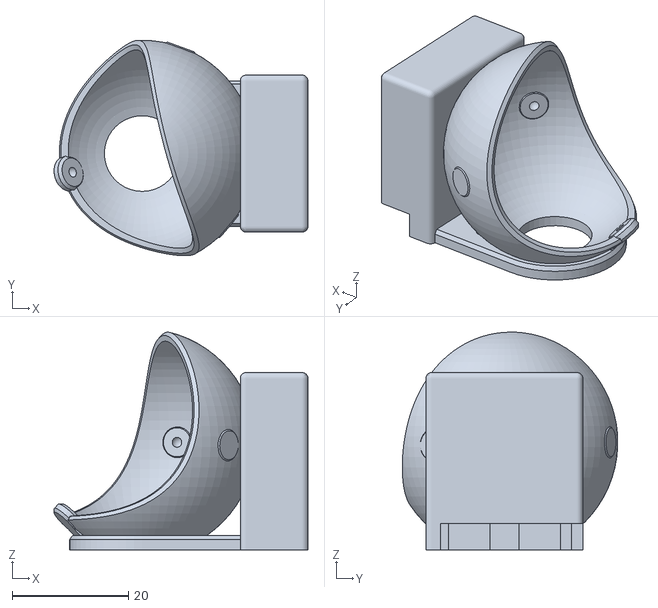
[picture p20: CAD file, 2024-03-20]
mtk/design/mtk64elt_STL/rev3/mtk64el_rev3_trackBallCase_RH.stl
43.7 x 37.1 x 37.5

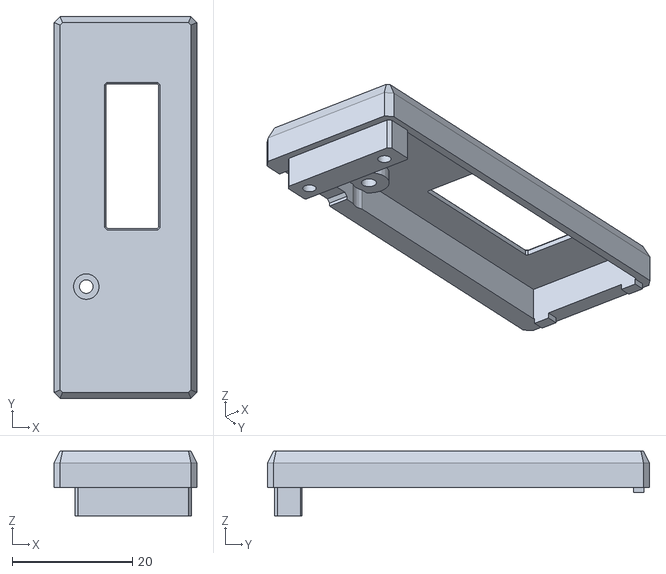
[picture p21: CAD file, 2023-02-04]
mtk/design/mtk64elp_STL/mtk64_PMCase_RH_rev4 v16.stl
23.8 x 63.5 x 10.8

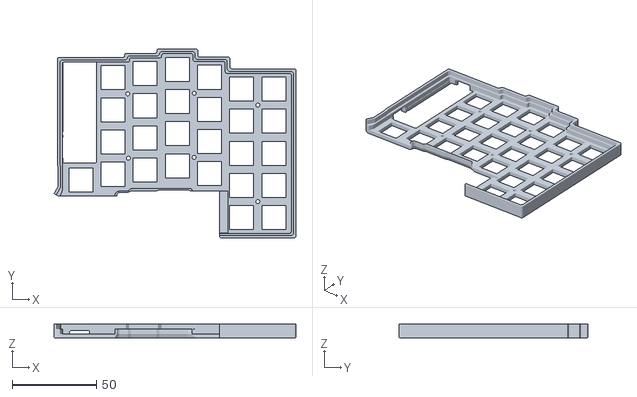
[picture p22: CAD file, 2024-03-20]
mtk/design/mtk64elt_STL/rev3/mtk64el_rev3_body_LH.stl
143.3 x 111.9 x 8.50

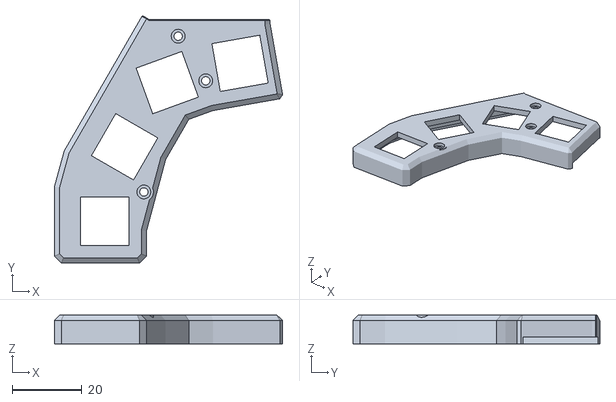
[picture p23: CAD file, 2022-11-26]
mtk/design/mtk64elp_STL/mtk64_TunmbLow_RH_rev4 v0.stl
65.5 x 70.9 x 8.20

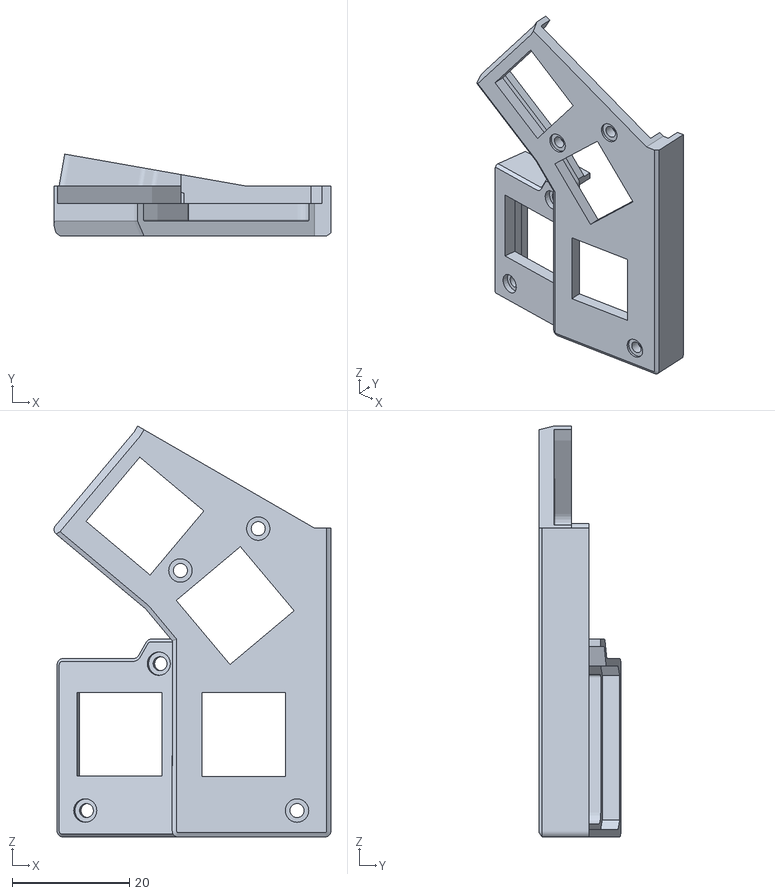
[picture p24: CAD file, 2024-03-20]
mtk/design/mtk64elt_STL/rev3/mtk64el_rev3_thumb_LH.stl
47.2 x 13.9 x 70.0

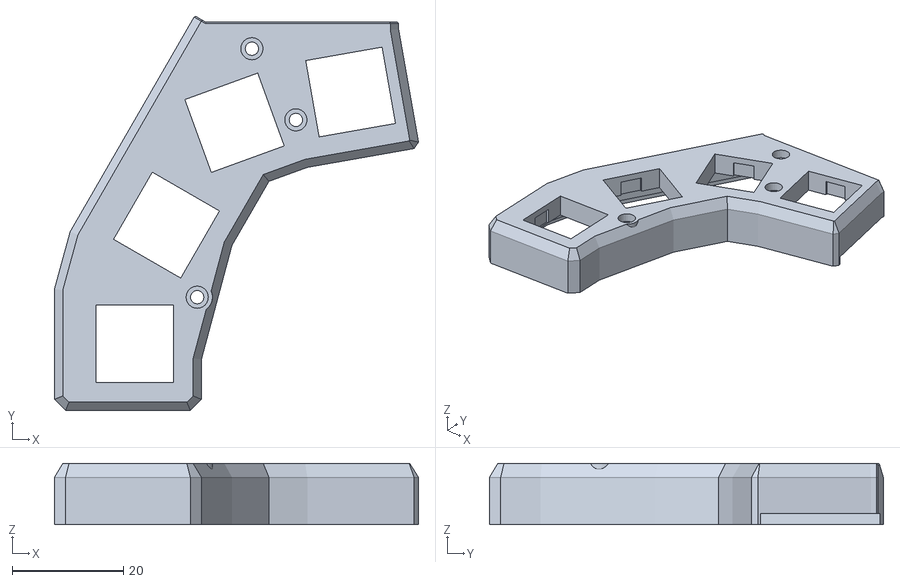
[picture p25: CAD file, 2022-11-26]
mtk/design/mtk64elp_STL/mtk64_Tunmb_RH_rev4 v0.stl
65.5 x 70.9 x 11.0

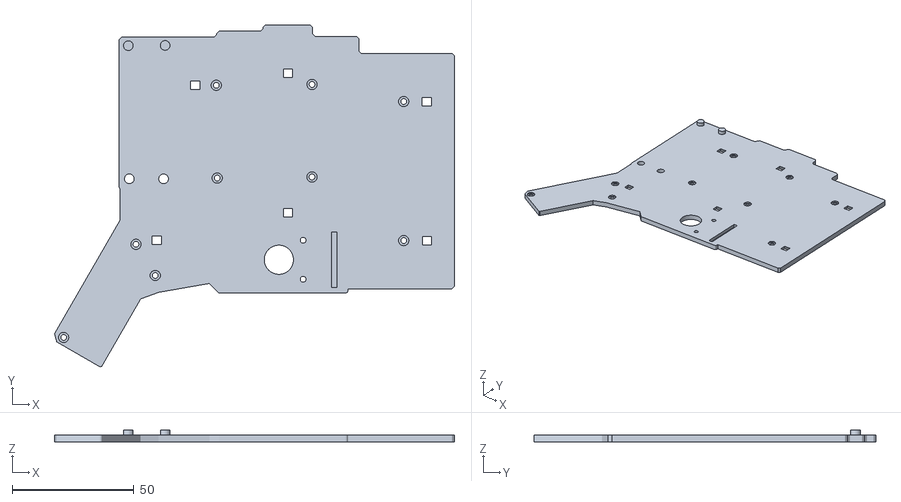
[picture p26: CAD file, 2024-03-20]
mtk/design/mtk64elt_STL/rev3/mtk64el_rev3_bottomPlateTrackballSide_RH.stl
164.4 x 140.5 x 4.75

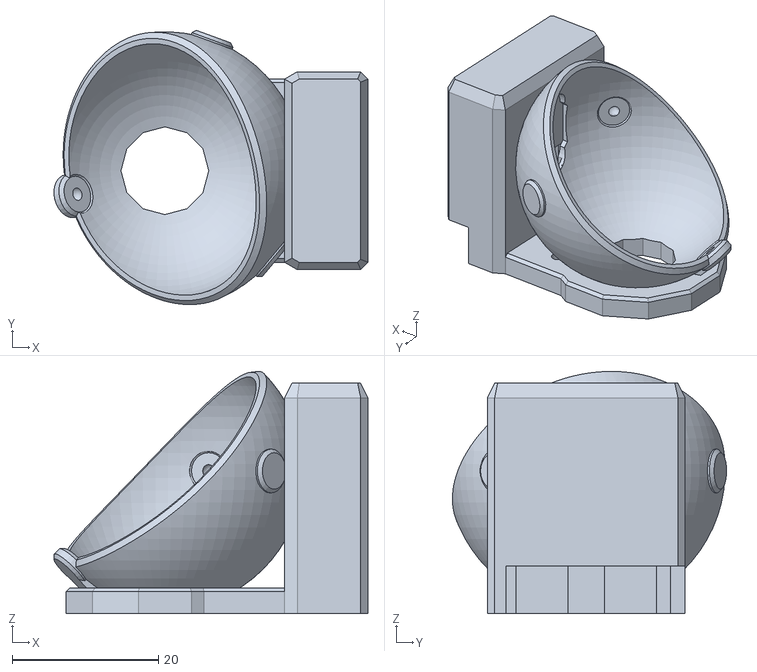
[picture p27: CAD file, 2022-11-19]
mtk/design/mtk64elp_STL/mtk64_BallCase_RH_rev3_v8.stl
42.9 x 37.5 x 33.1

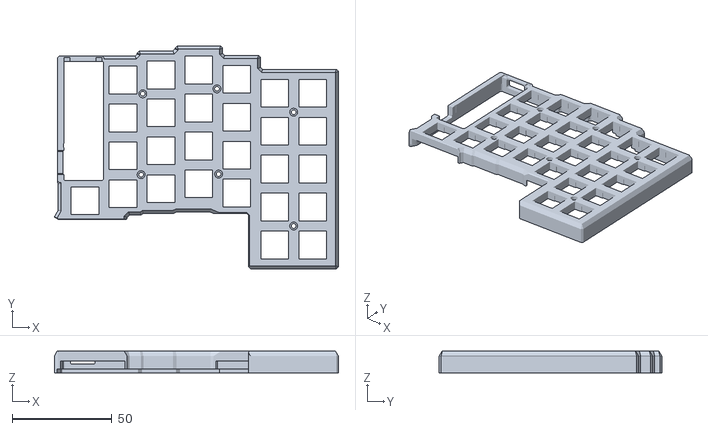
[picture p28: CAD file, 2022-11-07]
mtk/design/mtk64elp_STL/mtk64_BodyLP_RH_rev3 v7.stl
142.6 x 111.9 x 11.0

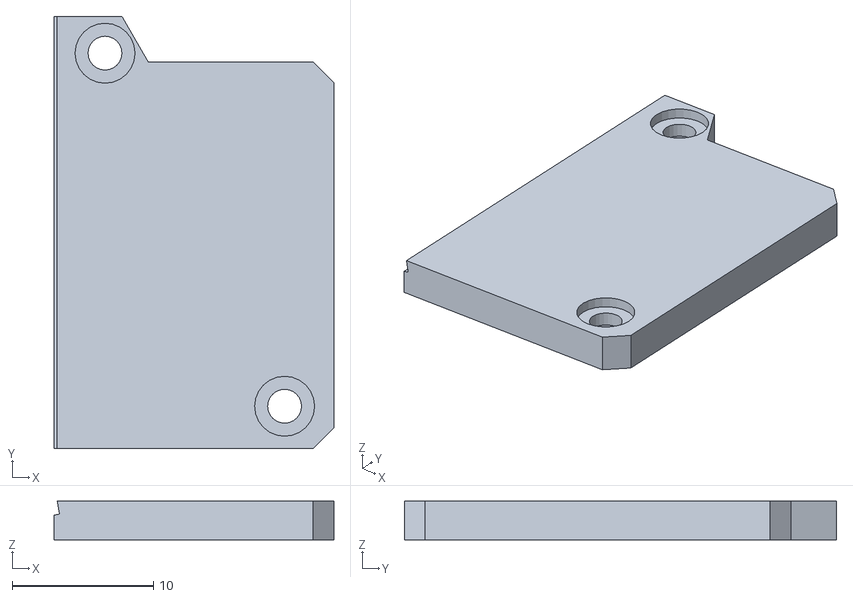
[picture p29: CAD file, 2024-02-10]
mtk/design/mtk64elt_STL/rev3/mtk64el_rev3_thumb_bottom_RH.stl
19.8 x 30.6 x 2.75

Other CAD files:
mtk/design/mtk64elt_STL/rev3/mtk64el_rev3_top_LH.stl
mtk/design/mtk64elt_STL/rev3/mtk64el_rev3_body_RH.stl
mtk/design/mtk64elt_STL/rev3/mtk64el_rev3_thumb_RH.stl
mtk/design/mtk64elp_STL/mtk64_Tunmb_RH_rev3 v4.stl
mtk/design/mtk64elp_STL/EC11E18244AU_Knob v1.stl
mtk/design/mtk64elp_STL/EC11E18244AU_Knob v6.stl
mtk/design/mtk64elp_STL/mtk64_BP_RH_rev2 v22.stl
mtk/design/mtk64elp_STL/mtk64_EncoderCase_RH_rev2 v26.stl
mtk/design/mtk64elp_STL/mtk64_PMCase_RH_rev2 v16.stl
mtk/design/mtk64elp_STL/mtk64_TunmbLow_RH_rev3 v6.stl
mtk/design/mtk64elt_STL/rev1/mtk64elt_TentLeg_RH_rev1.stl
mtk/design/mtk64elt_STL/rev1/mtk64elt_ballCase_RH_rev1.1.stl
mtk/design/mtk64elt_STL/rev1/mtk64elt_ballCase_RH_rev1.stl
mtk/design/mtk64elt_STL/rev1/mtk64elt_body_RH_rev1.stl
mtk/design/mtk64elt_STL/rev1/mtk64elt_bottomPlate_ThumbExtra_RH_rev1.stl
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

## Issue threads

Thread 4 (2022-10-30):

無題

isvc2027i, 2022-10-30:
@mentako-ya
こんにちは。
先日、メルカリで左右トラックボールの試作品を購入させていただいたものなのですが、
LEDの点灯不良がその後も発生してしまっているため、修理のほうをお願いしたく、
以下アドレスまで、返送先をご連絡お願いできますでしょうか。
よろしくお願いいたします。

mentako-ya, 2022-11-02:
ご連絡ありがとうございます。
修理品の送付先について、メールにてお送りいたしました。
よろしくお願いいたします。

Closed 2022-11-02.

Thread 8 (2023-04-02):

設定が反映されないキーに関しまして質問です

honokani, 2023-04-02:
こんにちは、mtk64eを利用させていただいています。

現状：
* 以下の引用の手順に従って自身でコードを編集しhexファイルを作成・flashしています。
    > ご自身でファームウェアをカスタマイズ、ビルドする場合
    > [via firmware ビルドガイド](https://github.com/mentako-ya/mtk/blob/main/qmk_firmware/keyboards/mtk)

* ほとんど問題なく変更箇所が動作したのですが、以下のキーの設定が反映されません。
    * 左手側キーボードの２つあるロータリーエンコーダのうち左側の、左右回転と押下ボタン
    * 右手側キーボードの親指用の４並んだキーのうち、左から２つ目
* 具体的には[こちら](https://github.com/honokani/mtk/blob/dev_mykey/qmk_firmware/keyboards/mtk/mtk64e/keymaps/via_mykey/keymap.c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)のようにコードを修正しています。
（記載のコードはテストのため`KC_A`や`KC_B`、`KC_F`などに変更しています。）
* そのほか
    * ロータリーエンコーダのうち右側は、変更したキーマップを反映・動作できています。
    * トラックボールは問題なく動作しています。

質問内容：
* これらのキーの動作に関して、キーマップを変更する以外に必要な設定はありますでしょうか。
設定すべき項目や、そもそも設定すべき箇所が間違っているなどご教示いただけたらと思います。

mentako-ya, 2023-04-13:
すみません。こちらのIssuuesを確認しておらず返信遅くなってしまいました。
こちらは解決されていますでしょうか。

修正されていたブランチのソースをビルドして手持ちのキーボードで確認してみると、左手外側のエンコーダーの回転ではcとdが入力されました。
[このコメントアウト](https://github.com/honokani/mtk/blob/dev_mykey/qmk_firmware/keyboards/mtk/mtk64e/keymaps/via_mykey/keymap.c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)によりエンコーダーの順序がずれているようですが、コメントアウトを戻せばKC_A ,KC_Bが入力されると思われます。
右手側キーボードの親指用の４並んだキーのうち、左から２つ目はｆが入力されました。

元のファームウェアに入れ替えてみて、キーマップのリセットをしても入力できない場合、物理的な故障で入力ができていないのかもしれません。
キースイッチの変更時のピン折れなども考えられますが、ピンが折れていないのに入力できないキーがある場合や、動作が不安定になっている場合、プロマイクロのコンスルーが抜けかけているかもしれません。
type-c端子に刺したケーブルを上に引っ張ったりすると、コンスルーが抜けてしまいます。
背面のアクリルの穴からプラスネジ二本を外して、プロマイクロのカバーと、OLEDを外してプロマイクロをしっかり基板に押し付けてみてください。

honokani, 2023-04-17:
いえ、とんでもないです
助かりました！

> [このコメントアウト](https://github.com/honokani/mtk/blob/dev_mykey/qmk_firmware/keyboards/mtk/mtk64e/keymaps/via_mykey/keymap.c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)によりエンコーダーの順序がずれているようですが、コメントアウトを戻せばKC_A ,KC_Bが入力されると思われます。

こちらの私の誤りを修正すると、ズレの解消と同時に、意図していた配列で正常動作するようになりました。
余計なコメントアウトをしていた原因はエンコーダ設定とレイヤー数の設定を混同していたためでした…。

お手数おかけいたしました。ありがとうございますm(_ _)m

Closed 2023-04-17.

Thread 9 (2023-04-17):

VIAでvia.jsonファイルが読み込めません

masatojpn, 2023-04-17:
mtk64eを使わせていただいております。

質問させてください。

VIA(https://usevia.app/) で `mtk64e_via.json` をアップロードすると、添付のようにエラーとなってしまうようです。
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

mentako-ya, 2023-04-22:
mtk64e_via.jsonはremap用に作成されています。
フォーマットが異なるので、そのままではuseviaで使用できません。

ファームウェア自体もremapで使用するためにqmk_firmwareのver.18以前を使用しています。
ver.19以降のqmk_firmwareとはキーコードの互換性がないので、useviaでは一部のキーのマッピングができないと思います。

サリチル酸さんの記事にremapとviaの違い（qmk_firmwareのバージョンの違い）について記載されています。
https://salicylic-acid3.hatenablog.com/entry/via-support

Closed 2023-08-15.

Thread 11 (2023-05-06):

RGBLIGHT_ENABLEをnoにしてビルドしたファームウェアではトラックボールの操作ができなくなる

hamhamburger, 2023-05-06:
用意されていたviaファームウェアで容量削減のためRGBLIGHT_ENABLEをnoにしたファームウェアではトラックボールの操作ができなくなってしまいました。
コンパイル自体は通りますし書き込みも正常に行えています。

RGBLIGHT_ENABLEをifdefで見ている部分にトラックボールのコードが入ってしまっているのかと思いましたがそういうわけでもなさそうです。

自分はqmkのコードについて素人なので何か勘違いがあるかもしれません。
一度お手すきの際に確認していただけると助かります。

hamhamburger, 2023-05-09:
ご回答ありがとうございます。
説明が足りず申し訳ありません。
トラックボールの操作ができなくなるとはトラックボールによるカーソル移動ができなくなるという意味です。
oledでレイヤーのデバッグをしてみましたがトラックボールが動いていないのでレイヤーも切り替わっていませんでした。

qmkのバージョンは0.16.3
構成は右トラックボール左ロータリーエンコーダ
LED無し
です

ただこれはコードの問題というよりqmkの問題かもしれないのでバージョンを変えて試してみます。

Closed 2023-08-15.

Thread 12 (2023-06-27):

ボールケースの３Dプリントが出来ない

bee-tk, 2023-06-27:
以下のファイルを３Dプリントしたいのですが、エラーが発生しておりプリントできません。
https://github.com/mentako-ya/mtk/blob/main/mtk/design/mtk64elp_STL/mtk64_BallCase_RH_rev3_v8.stl

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

すみませんが、プリント可能なファイルを提供していただくことは出来ないでしょうか？

mentako-ya, 2023-06-28:
エラーが発生しているとのことですが、私の環境（Mac版PrusaSlicer2.5.1)ではエラーを再現できず、STLファイルを再出力しても変わりがありませんでした。
発生しているエラーはどのような内容でしょうか。

スクリーンショットのスライサーが何のスライサーかわからず、エラーの理由がわかりませんが、
画面上にビルドプレートが写っていないようですので、サイズが大きすぎてビルドプレートに収まらないためにエラーになっているのでしょうか。

スライサーによっては、STLファイルを読み込む際の標準のスケールがインチになっているものがあります。
PrusaSlicerの場合、STLファイルをインポートする際に
ファイル＞インポート＞STLのインポートを選ぶと、インポート時のスケールがインチになってしまい、巨大なボールケースになってしまうので、ビルドプレートに収まらず、エラーになります。

PrusaSlicerでミリスケールでSTLをインポートする場合、
ファイル＞インポート＞STL/3MF/STEP/OBJ/AMFのインポートを使用して、ミリ単位でインポートを行う必要があります。

bee-tk, 2023-06-30:
返信ありがとうございます。手元では再現できないとのこと承知しました。

実はこちらのファイルを3Dプリントするため発注したところから、その図の通りエラーが発生したとの内容のメールのみで詳細のエラー内容も分からないという状況でした…
ただ、stepファイルがあれば解決できるとのことでした。
私自信stlファイルの作成に関する知識が無いため、非常に抽象的な質問となってしまいすみませんでした。

mentako-ya, 2023-06-30:
画面右下のエラーの明細らしき画面を見ると、一番上の１行目のSurface（mm2）の値が3294になっています
3294平方ミリメートルですと正方形に直すと縦62.6mm✖︎横62.6mmに相当します。
ボールケースのサイズはX 43mm Y 37mm Z 33mm くらいですので、62.6x62.6mmのサイズのSurfaceはありえないと思います。
やはり、STLファイルの読み込みが、インチ単位で行われているのではないでしょうか。
１インチ＝25.4ミリですので、62.6÷25.4=2.46ミリくらいが本来のSurfaceの値なのだと思います。

JLCPCBの3Dプリント https://3d.jlcpcb.com
でSTLファイルをアップロードしたところ、ｍｍ単位で正常にロードできていました。
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

mm単位でファイルをロードするなどロード方法を変えてもらうか、業者を変えてみてはいかがでしょうか。

bee-tk, 2023-07-01:
なるほどです。
jlcpcbに発注依頼したこともあるのですが、レビュー時に同様のエラーが出て解決してくださいと言われていました。
ロード方法についてmm単位にできないか、相談してみようと思います。

調査いただきありがとうございました。

Closed 2023-07-30.

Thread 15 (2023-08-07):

PMW3389センサーで自動マウスレイヤー切替をオフにしたい時のファームウェアについて

nakatsu0213, 2023-08-07:
rev2基板
PMW3389センサー
左ロータリーエンコーダー
右ボール用
上記の構成で自動マウスレイヤー切替をオフにしたい場合、mtk_mtk64e_via.hexを導入可能でしょうか？
それとも別途ファームウェアをビルドする必要がありますでしょうか。

mentako-ya, 2023-08-07:
mtk_mtk64e_via.hexはPMW3360のドライバーを組み込んでいるため、PMW3380では使用できません。
現在のmasterブランチのソースコードから[#define AUTO_MOUSE_LAYER_ENABLE](https://github.com/mentako-ya/mtk/blob/bcf12c0d4c112c3ad22d71f2d6e688836932c6ba/qmk_firmware/keyboards/mtk/mtk64e/keymaps/via/config.h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)の指定を削除してビルドすれば、自動マウスレイヤー切り替え無しのPMW3389版ドライバーがビルドできると思います。（手元に検証できる環境がないため、未確認です）

nakatsu0213, 2023-08-08:
教えていただいた形でビルドをかけて、ざっくりですが動かしてみた所、こちらの望んだ形で動作しました。
ありがとうございました。

Closed 2023-08-08.

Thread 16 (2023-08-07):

Layer1のマッピングについて

nakatsu0213, 2023-08-07:
デフォルトのキーマップについて
`レイヤー１:Shiftキー押下相当（大文字入力や記号入力）`
とのことですが、
Layer0の以下2キーのみを変更した時
* MO(0)→Shift
* Layer(1)→全く別の機能

Layer1は使われない認識であっていますでしょうか
(検証してみて、Shift長押しではLayer1を使用せずに大文字や記号が入ることを確認したのですが、念のため私になにか見落としがないかの確認をさせてください。)

mentako-ya, 2023-08-07:
MO(0)→Shiftに変更する場合、デフォルトのマッピングでLeyer1を使用する必要はありません。
もっとキー数の少ないキーボードで数字キーがないレイアウトでは、Leyer1に数字キー部分のキーをマッピングすると思いますが、本キーボードはキー数が十分にあるので、無理にLeyer1を使用する必要はないと思います。

nakatsu0213, 2023-08-07:
ご回答ありがとうございました！

Closed 2023-08-07.

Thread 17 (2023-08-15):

RemapのMouse Whが機能しない

nakatsu0213, 2023-08-15:
ロータリーエンコーダにマウススクロール上下左右を割り当てたくてRemapでMouseWhを割り当てましたが機能しないように見えます

ファームウェアは純正の[mtk_mtk64e_PMW3389_AutoMouseLayer_via.hex](https://raw.githubusercontent.com/mentako-ya/mtk/main/mtk/mtk_mtk64e_PMW3389_AutoMouseLayer_via.hex)を使用しています

mentako-ya, 2023-08-15:
マウスのホイール操作をキーマップで有効化する場合、MOUSEKEY_ENABLE をyesにしてビルドする必要があります。
ただし、そのままではファームウェアサイズが上限を超えるので、RGBLIGHT_ENABLEをnoにするなど、ファームウェア容量が上限を超えないよう調整が必要です。

https://github.com/mentako-ya/mtk/blob/bcf12c0d4c112c3ad22d71f2d6e688836932c6ba/qmk_firmware/keyboards/mtk/mtk64e/rules.mk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

nakatsu0213, 2023-08-15:
ご回答ありがとうございます。
ここらへんはqmk_firmwareの話っぽいですね、失礼しました。

Closed 2023-08-15.

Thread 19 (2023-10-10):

新ファームウェアでのロータリーエンコーダの挙動について

nakatsu0213, 2023-10-10:
新仕様Remapに対応いただけたとのことで、ファームウェアを導入して検証してみたところ
ロータリーエンコーダを回したときに発生するキーコードがPageUpかPageDownのいずれかのみになります
ファームウェア導入直後、EEPROMリセット直後、Remap上でそれぞれ上下左右キーを割り振っても、
abcdを割り振っても常に同様です。
（左右どちらのつまみを左に回してもPageUp、右に回してもPageDownになります。
こちらで確認した範囲で押し込み動作は問題ないように見受けられます）

使用したファームウェア類は
mtk_mtk64e_PMW3360_AutoMouseLayer_via.0.22.hex
mtk64e_via.json
で、それぞれ今朝DLしたものになります。

※キーコードの確認は以下で確認しています
https://www.ipentec.com/utils/WebKeyCode/

mentako-ya, 2023-10-11:
qmk_firmware 0.22ではencoder_update_kbを実装してencoder_update_userをコールする必要があったようです。
以下の修正版ファームウェアをコミットしました
mtk_mtk64e_PMW3360_AutoMouseLayer_via.0.22.hex
mtk_mtk64e_PMW3389_AutoMouseLayer_via.0.22.hex

nakatsu0213, 2023-10-11:
確認したところ、ロータリエンコーダ周りの不具合は解消されていました。
ご対応ありがとうございました。

Closed 2023-10-11.

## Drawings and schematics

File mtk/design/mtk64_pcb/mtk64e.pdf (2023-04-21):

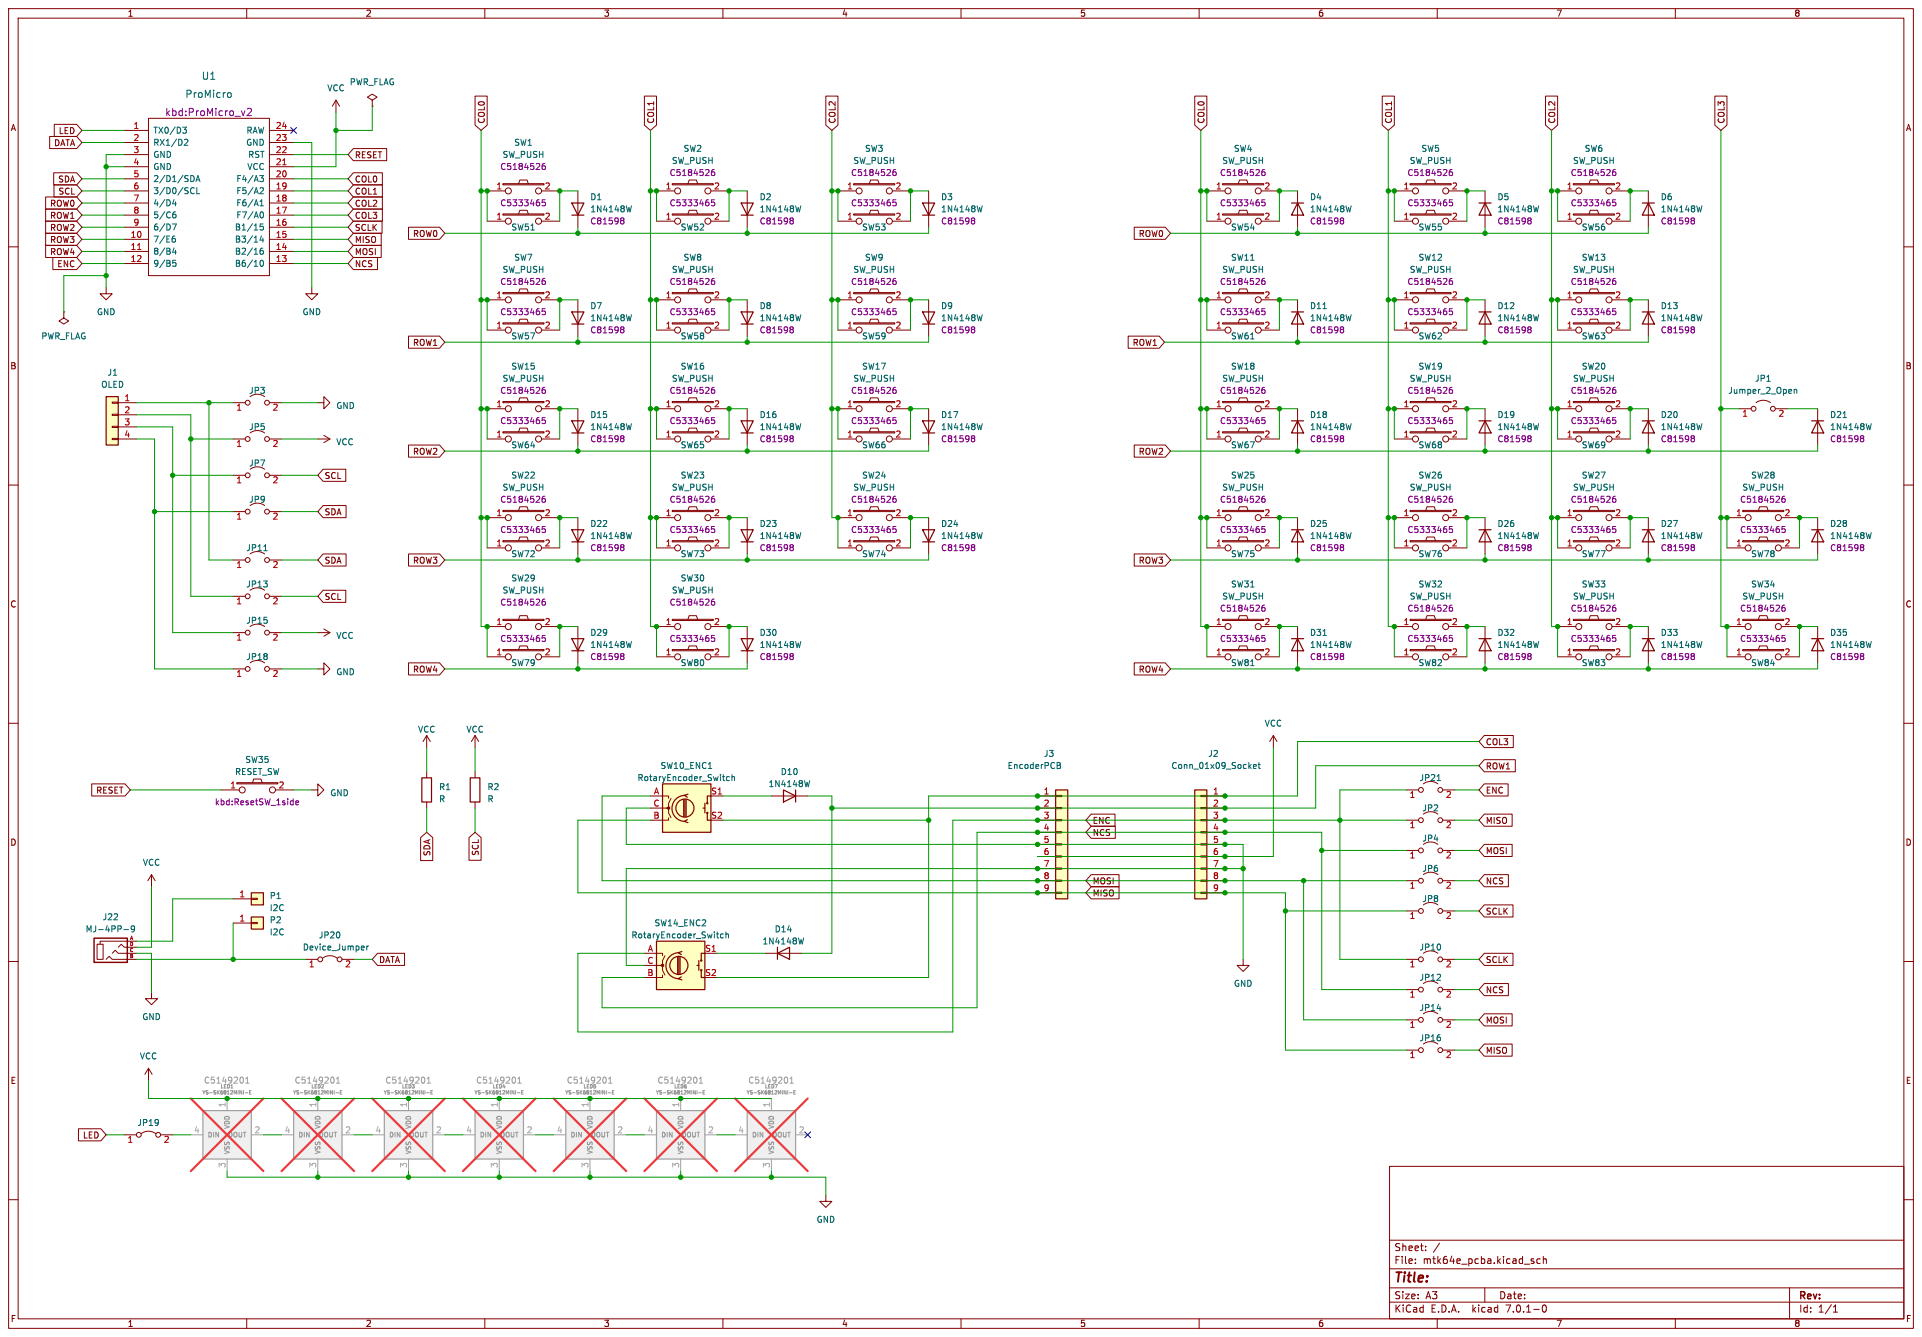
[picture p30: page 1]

Id: 1/1 Title: File: mtk64e_pcba.kicad_sch Sheet: /

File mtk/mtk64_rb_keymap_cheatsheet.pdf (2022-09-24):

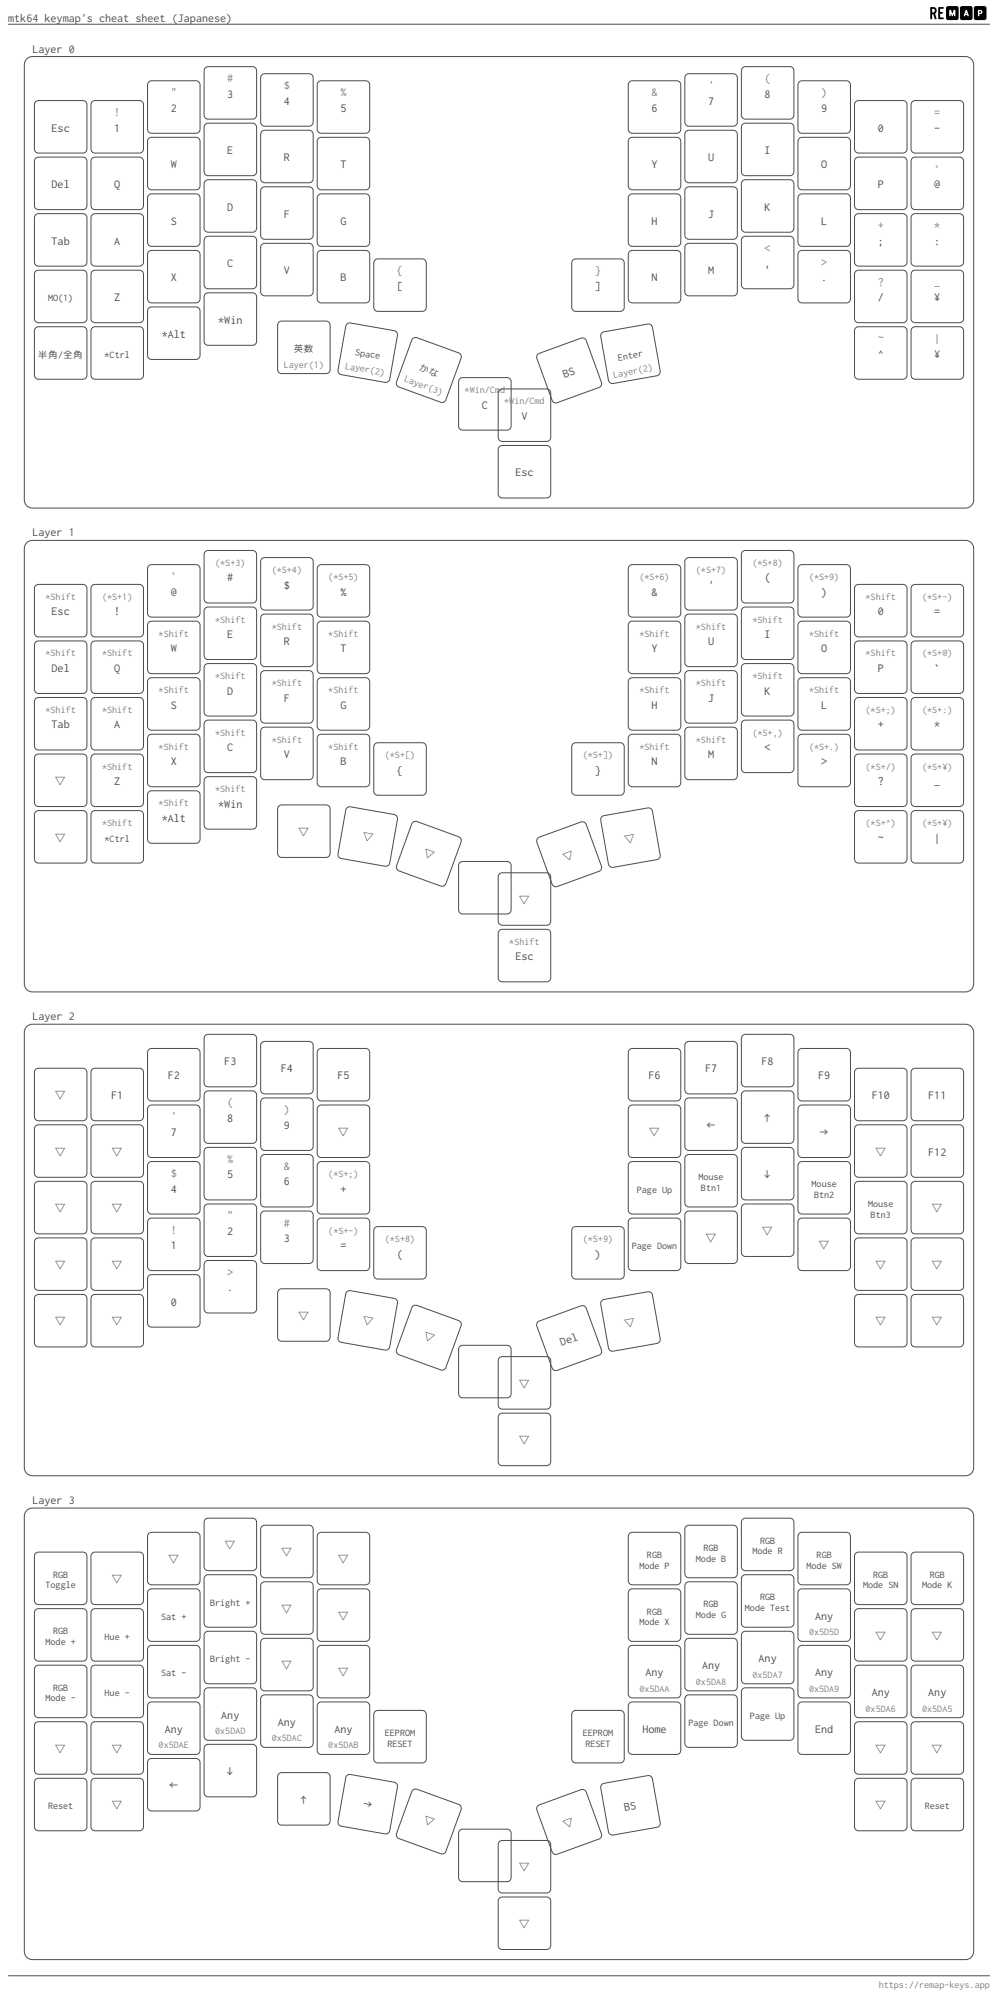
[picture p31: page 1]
Layer 0; Esc; Del; Tab; *Win; *Alt; 英数 Layer(1); *Ctrl; *Win/Cmd C; *Win/Cmd V; Space Layer(2); かな Layer(3); Enter Layer(2); Layer 1; (*S+9) ) *Shift; *Shift 0; *Shift E; *Shift I; *Shift R; *Shift U; *Shift W; *Shift T; *Shift Y; *Shift O *Shift; *Shift Q; *Shift P; *Shift D; *Shift K; *Shift F; *Shift J; *Shift S; *Shift G; *Shift H; *Shift L *Shift; *Shift A; *Shift C; *Shift V; *Shift M; *Shift X; *Shift B; *Shift N; *Shift Z; *Shift; *Shift *Ctrl; *Shift Esc; Layer 2; Mouse Btn1; Page Up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

mtk64 keymap's cheat sheet (Japanese)

Page Up Any

Page Down Any

https://remap-keys.app

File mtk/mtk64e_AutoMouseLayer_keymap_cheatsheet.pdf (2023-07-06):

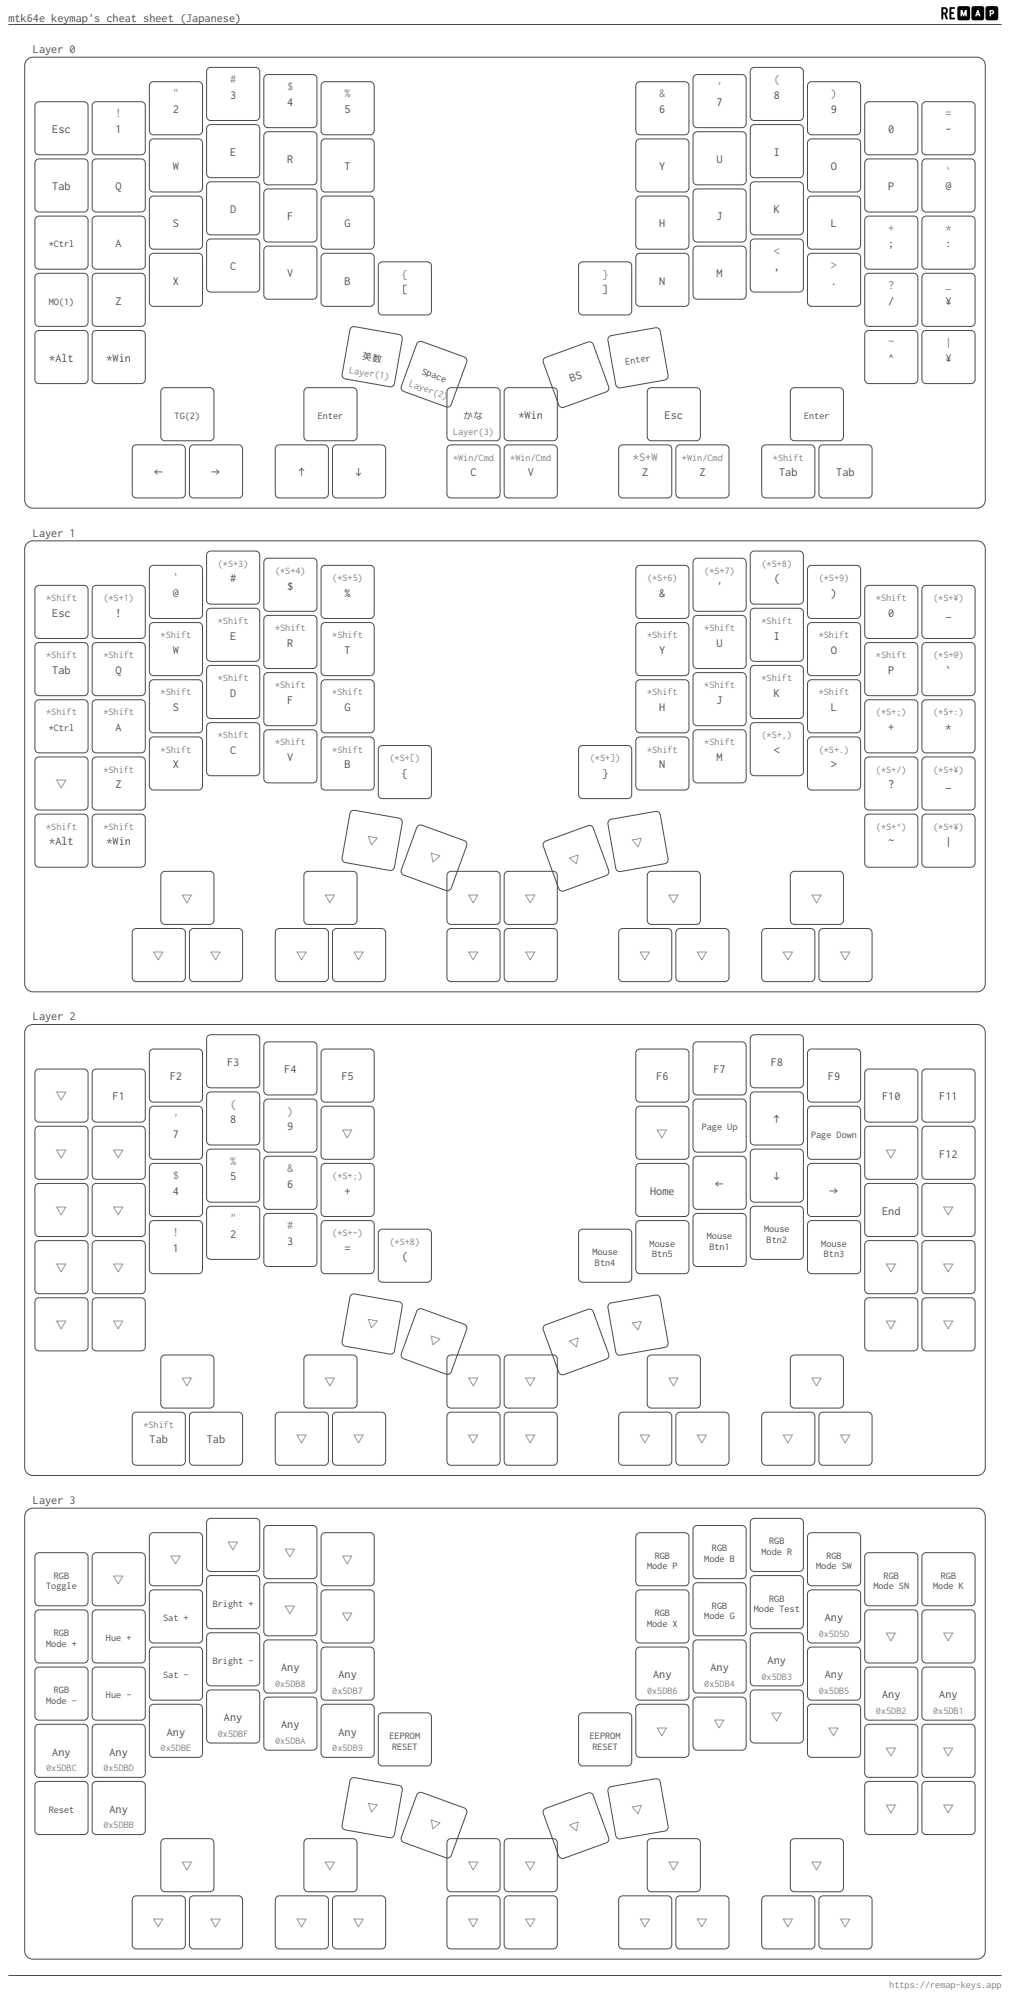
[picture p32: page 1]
Layer 0; Esc; Tab; *Ctrl; *Alt; *Win; Enter; Layer(3); *Win/Cmd C; *Win/Cmd V; *Win/Cmd Z; *Shift; 英数 Layer(1); Space Layer(2); Layer 1; (*S+9) ) *Shift; *Shift 0; *Shift E; *Shift I; *Shift R; *Shift U; *Shift W; *Shift T; *Shift Y; *Shift O *Shift; *Shift Q; *Shift P; *Shift D; *Shift K; *Shift F; *Shift J; *Shift S; *Shift G; *Shift H; *Shift L *Shift; *Shift A; *Shift C; *Shift V; *Shift M; *Shift X; *Shift B; *Shift N; *Shift Z; *Shift *Alt; *Shift *Win; Layer 2; Page Up; Page Down; Home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

mtk64e keymap's cheat sheet (Japanese)

https://remap-keys.app

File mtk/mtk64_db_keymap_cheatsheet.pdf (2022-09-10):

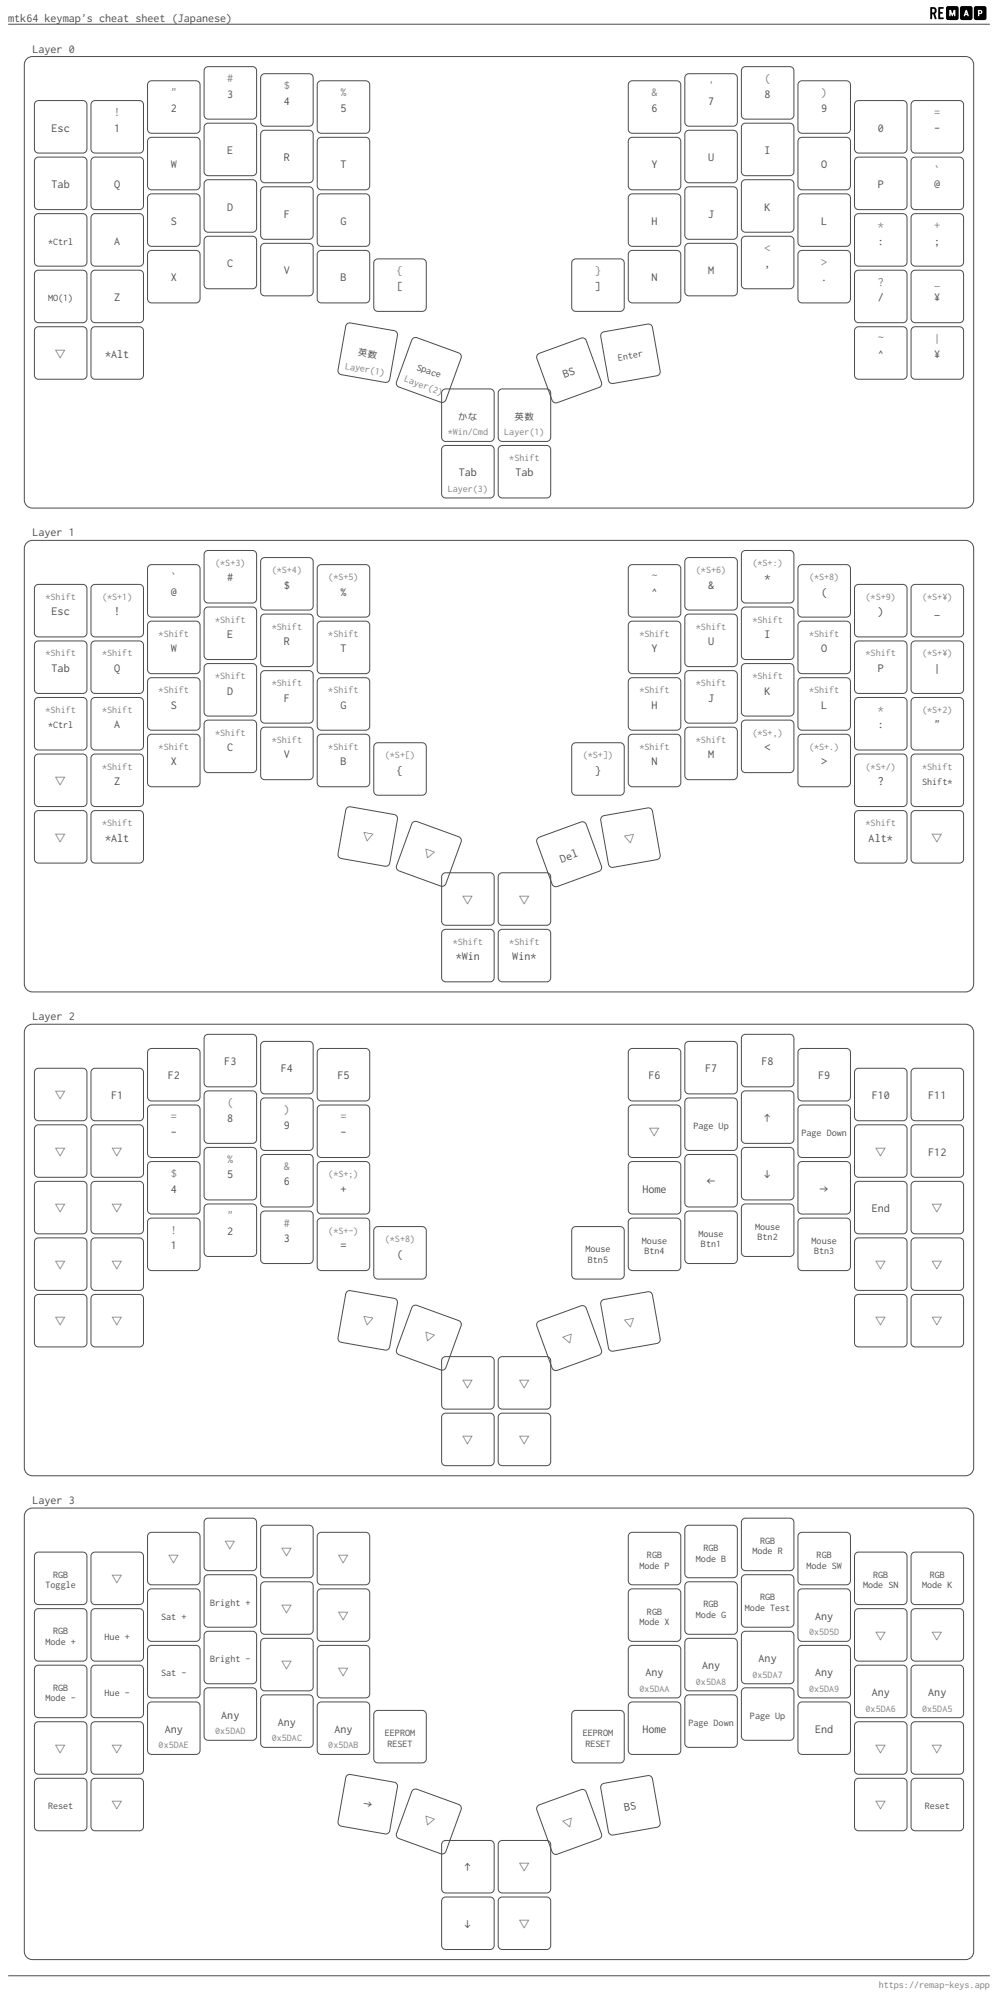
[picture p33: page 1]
Layer 0; Esc; Tab; *Ctrl; *Alt; かな *Win/Cmd; 英数 Layer(1); Layer(3); *Shift Tab; Space Layer(2); Enter; Layer 1; (*S+8) ( *Shift; *Shift E; *Shift I; *Shift R; *Shift U; *Shift W; *Shift T; *Shift Y; *Shift O *Shift; *Shift Q; *Shift P; *Shift D; *Shift K; *Shift F; *Shift J; *Shift S; *Shift G; *Shift H; *Shift L *Shift; *Shift A; *Shift C; *Shift V; *Shift M; *Shift X; *Shift B; *Shift N; *Shift Z; *Shift Shift*; *Shift *Alt; *Shift; Alt*; *Shift *Win; *Shift Win*; Del; Layer 2; Page Up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

mtk64 keymap's cheat sheet (Japanese)

Page Up Any

Page Down Any

https://remap-keys.app

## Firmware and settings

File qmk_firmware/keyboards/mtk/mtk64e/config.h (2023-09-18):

/*
Copylight 2022 Mentako_ya
Copyright 2021 @Yowkees
Copyright 2022 MURAOKA Taro (aka KoRoN, @kaoriya)

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
You should have received a copy of the GNU General Public License
along with this program.  If not, see <http://www.gnu.org/licenses/>.
*/

#pragma once

// Key matrix parameters (duplex matrix)
#define MATRIX_ROWS         (6 * 2)  // split keyboard
#define MATRIX_COLS         (4 * 2)  // duplex matrix
#define MATRIX_ROW_PINS     { D4, C6, D7, E6, B4 }
#define MATRIX_COL_PINS     { F4, F5, F6, F7 }
#define MATRIX_MASKED
#define DEBOUNCE            5

/* Rotary encoder */
#ifdef ENCODER_ENABLE
#define ENCODERS_PAD_A { B6, B3 }
#define ENCODERS_PAD_B { B5, B2 }
#define ENCODER_RESOLUTION 2
#endif

// Split parameters
#define SOFT_SERIAL_PIN         D2
#define SPLIT_HAND_MATRIX_GRID  F7, D7
#define SPLIT_USB_DETECT
#define SPLIT_USB_TIMEOUT       500
#define NO_SUSPEND_POWER_DOWN
#define USB_SUSPEND_WAKEUP_DELAY 200

#define SPLIT_TRANSACTION_IDS_KB KEYBALL_GET_INFO, KEYBALL_GET_MOTION, KEYBALL_SET_CPI

// RGB LED settings
#define WS2812_DI_PIN          D3
#ifdef RGBLIGHT_ENABLE
#    define RGBLED_NUM      74
#    define RGBLED_SPLIT    { 37, 37 }
#    ifndef RGBLIGHT_LIMIT_VAL
#        define RGBLIGHT_LIMIT_VAL  120 // limitated for power consumption
#    endif
#    ifndef RGBLIGHT_VAL_STEP
#        define RGBLIGHT_VAL_STEP   12
#    endif
#    ifndef RGBLIGHT_HUE_STEP
#        define RGBLIGHT_HUE_STEP   17
#    endif
#    ifndef RGBLIGHT_SAT_STEP
#        define RGBLIGHT_SAT_STEP   17
#    endif
#endif
#ifdef RGB_MATRIX_ENABLE
#    define RGB_MATRIX_SPLIT    { 37, 37 }
#endif

#ifndef OLED_FONT_H
#    define OLED_FONT_H "keyboards/mtk/lib/glcdfont.c"
#endif

#if !defined(LAYER_STATE_8BIT) && !defined(LAYER_STATE_16BIT) && !defined(LAYER_STATE_32BIT)
#    define LAYER_STATE_8BIT
#endif

// To squeeze firmware size
#undef LOCKING_SUPPORT_ENABLE
#undef LOCKING_RESYNC_ENABLE
#define LAYER_STATE_8BIT

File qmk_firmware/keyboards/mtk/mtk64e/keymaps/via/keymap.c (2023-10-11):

/*
Copyright 2022 mentako_ya

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
You should have received a copy of the GNU General Public License
along with this program.  If not, see <http://www.gnu.org/licenses/>.
*/

#include QMK_KEYBOARD_H
#include "quantum.h"

enum custom_keycodes {
    KC_TG_CLICKABLE = KEYBALL_SAFE_RANGE, //0x5DAF
    KC_TO_CLICKABLE_INC,                  //0x5DB0
    KC_TO_CLICKABLE_DEC,                  //0x5DB1
    KC_TO_RESET_INC,                      //0x5DB2
    KC_TO_RESET_DEC,                      //0x5DB3
};

#ifdef AUTO_MOUSE_LAYER_ENABLE

enum click_state {
    NONE = 0,
    WAITING,    // マウスレイヤーが有効になるのを待つ。 Wait for mouse layer to activate.
    CLICKABLE,  // マウスレイヤー有効になりクリック入力が取れる。 Mouse layer is enabled to take click input.
};

typedef union {
  uint64_t raw;
  struct {
	bool tg_clickable_enabled;
    int16_t to_clickable_movement;
    int16_t to_reset_time;
  };
} user_config_t;

user_config_t user_config;

enum click_state clstate;     // 現在のクリック入力受付の状態 Current click input reception status
uint16_t click_timer;       // タイマー。状態に応じて時間で判定する。 Timer. Time to determine the clstate of the system.
const uint16_t normal_layer = 0;   // 初期レイヤー　初期レイヤー以外でマウス操作した場合、レイヤーの自動切り替えをしない。
const uint16_t click_layer = 2;   // マウス入力が可能になった際に有効になるレイヤー。Layers enabled when mouse input is enabled

int16_t mouse_movement;

void eeconfig_init_user(void) {
    user_config.raw = 0;
    user_config.tg_clickable_enabled = true;
    user_config.to_clickable_movement = 100;
    user_config.to_reset_time = 10;
    eeconfig_update_user(user_config.raw);
}

// クリック用のレイヤーを有効にする。　Enable layers for clicks
void enable_click_layer(void) {
    layer_on(click_layer);
    click_timer = timer_read();
    clstate = CLICKABLE;
}

// クリック用のレイヤーを無効にする。 Disable layers for clicks.
void disable_click_layer(void) {
    clstate = NONE;
    layer_off(click_layer);
}

// 自前の絶対数を返す関数。 Functions that return absolute numbers.
int16_t my_abs(int16_t num) {
    if (num < 0) {
        num = -num;
    }

    return num;
}

// 自前の符号を返す関数。 Function to return the sign.
int16_t mmouse_move_y_sign(int16_t num) {
    if (num < 0) {
        return -1;
    }

    return 1;
}

// 現在クリックが可能な状態か。 Is it currently clickable?
bool is_clickable_mode(void) {
    return clstate == CLICKABLE;
}

bool process_record_user(uint16_t keycode, keyrecord_t *record) {
    
    switch (keycode) {

        case KC_TG_CLICKABLE:
            if (record->event.pressed) {
            	user_config.tg_clickable_enabled = !user_config.tg_clickable_enabled;
                eeconfig_update_user(user_config.raw);
            }
            return false;
        
        case KC_TO_CLICKABLE_INC:
            if (record->event.pressed) {
                user_config.to_clickable_movement += 5; // user_config.to_clickable_time += 10;
                eeconfig_update_user(user_config.raw);
            }
            return false;

        case KC_TO_CLICKABLE_DEC:
            if (record->event.pressed) {
                user_config.to_clickable_movement -= 5; // user_config.to_clickable_time -= 10;
                if (user_config.to_clickable_movement < 5)
                {
                    user_config.to_clickable_movement = 5;
                }
                eeconfig_update_user(user_config.raw);
            }
            return false;

        case KC_TO_RESET_INC:
            if (record->event.pressed) {
                user_config.to_reset_time += 1;
                if (user_config.to_reset_time > 999)
                {
                    user_config.to_reset_time = 999;
                }
                eeconfig_update_user(user_config.raw);
            }
            return false;

        case KC_TO_RESET_DEC:
            if (record->event.pressed) {
                user_config.to_reset_time -= 1;
                if (user_config.to_reset_time < 1)
                {
                    user_config.to_reset_time = 1;
                }
                eeconfig_update_user(user_config.raw);
            }
            return false;

        default:
            if  (record->event.pressed) {

                if (clstate == CLICKABLE)
                {
                	// CLICKABLEの状態でクリックした場合、CLICKABLEを延長
                    enable_click_layer();
                }

            }
        
    }
   
    return true;
}

report_mouse_t pointing_device_task_user(report_mouse_t mouse_report) {

    if (mouse_report.x != 0 || mouse_report.y != 0) {
        
        switch (clstate) {
            case CLICKABLE:
                click_timer = timer_read();
                break;

            case WAITING:
                /*
                if (timer_elapsed(click_timer) > user_config.to_clickable_time) {
                    enable_click_layer();
                }
                */
            	if (user_config.tg_clickable_enabled == false){
            		// CLICKABLE無効
            		break;
            	}

            	if (normal_layer != get_highest_layer(layer_state)){
            		// CLICKABLEになる前から初期レイヤー以外になっている場合、CLICKABLEにしない
            		 break;
            	}

                mouse_movement += my_abs(mouse_report.x) + my_abs(mouse_report.y);

                if (mouse_movement >= user_config.to_clickable_movement)
                {
                    mouse_movement = 0;
                    enable_click_layer();
                }
                break;

            default:
                click_timer = timer_read();
                clstate = WAITING;
                mouse_movement = 0;
        }
    }
    else
    {
        switch (clstate) {
            case CLICKABLE:
                if (timer_elapsed(click_timer) > (user_config.to_reset_time * 100)) {
                    disable_click_layer();
                }
                break;

            case WAITING:
                if (timer_elapsed(click_timer) > 50) {
                    mouse_movement = 0;
                    clstate = NONE;
                }
                break;

            default:
                mouse_movement = 0;
                clstate = NONE;
        }
    }

    return mouse_report;
}

layer_state_t layer_state_set_user(layer_state_t state) {
    // Auto enable scroll mode when the highest layer is 3
    keyball_set_scroll_mode(get_highest_layer(state) == 3);

    // CLICKABLEな状態でレイヤー切替が発生した場合
    if (clstate == CLICKABLE) {
    	// clstateをNONEにしておくことで、意図せずマウスレイヤーが解除されないようにする
    	clstate = NONE;
    	if((state & ~(0b0001 << click_layer)) != 0b0000){
    		//マウスレイヤー以外が有効な場合、マウスレイヤーを無効化
    		state &= ~(0b0001 << click_layer);
    	}
    }

    return state;
}

#endif

#ifndef AUTO_MOUSE_LAYER_ENABLE

layer_state_t layer_state_set_user(layer_state_t state) {
    // Auto enable scroll mode when the highest layer is 3
    keyball_set_scroll_mode(get_highest_layer(state) == 3);
    return state;
}
#endif

#ifdef OLED_ENABLE

#    include "lib/oledkit/oledkit.h"
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

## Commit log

2022-09-10 左右両ボール用via.json
2022-09-10 mtk64 double ball keymap cheetsheet追加
2022-09-24 define TAP_CODE_DELAY for common keymaps #132 https://github.com/Yowkees/keyball/pull/132 matrix_mask修正 Row4 Col3 使用可能
    [config.h]
2022-09-25 Encoder有効 Console有効 RGB無効
2022-10-02 ピンアサイン修正
2022-10-02 readme修正
2022-10-02 コンソール出力無効化
2022-10-08 KiCadデータ追加
    [KeyBall-BOM.csv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]
2022-10-08 B5 配線追加
2022-10-08 親指追加キーのダイオード反転
2022-10-10 シルクプリント追加、ペースト追加 JCLPCB order
    [mtk64_R_rev2-B_Cu.gbr, mtk64_R_rev2-B_Mask.gbr, mtk64_R_rev2-B_Paste.gbr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]
2022-10-10 コミット漏れ追加
2022-10-15 Edge.Cut修正
2022-10-18 mtk64_rev2 STL 初期コミット
    [CE3_PEC12R-4025F-S0024_Knob v2.3mf, CE3_PEC12R-4222F-S0024_Knob v2.3mf, CE3_mtk64_BP_LH_rev2 v13.3mf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]
2022-10-18 エッジ修正
    [CE3_mtk64_BP_LH_rev2 v13.3mf, CE3_mtk64_BP_LH_rev2 v22.3mf, CE3_mtk64_BP_RH_rev2 v13.3mf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]
2022-10-22 左右ロータリーエンコーダーレイアウトマッピング
2022-10-23 キーマップ修正
2022-10-23 Encoder周辺修正
    [CE3_PEC12R-4025F-S0024_Knob v2.3mf, CE3_PEC12R-4025F-S0024_Knob v3.3mf, CE3_PEC12R-4222F-S0024_Knob v2.3mf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]
2022-10-24 エンコーダーマッピング修正
2022-10-24 レイアウトをDual固定に変更
2022-10-24 mtk64eに名称変更
2022-10-24 mtk64eキーマップチートシート
2022-10-24 キーマッピング修正
2022-10-26 配線漏れ修正 geverファイル再出力
    [mtk64_R_rev2-B_Cu.gbr, mtk64_R_rev2-B_Mask.gbr, mtk64_R_rev2-B_Paste.gbr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]
2022-10-26 readme mtk64e追加
2022-10-26 readme イメージファイル修正
2022-11-06 mtk64e左ボールファームウェア追加
2022-11-07 親指ロープロケース
    [CE3_mtk64_BodyLP_LH_rev3 v7.3mf, CE3_mtk64_BodyLP_RH_rev3 v7.3mf, CE3_mtk64_TumbLow_LH_rev3 v7.3mf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]
2022-11-11 Update README.md
    トラックボール設定のコード値 mtk64e 追記
2022-11-12 Update README.md
    キーボードの接続について追記
2022-11-19 mtk64e lowprofile case data
    [CE3_EC11E18244AU_Knob_x4 v1.3mf, CE3_mtk64_BP_LH_rev2 v22.3mf, CE3_mtk64_BP_RH_rev2 v22.3mf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]
2022-11-19 左ボール時 B2 MOSI 配線修正
2022-11-19 親指キーフットプリント置き換え準備
2022-11-22 親指キー内向きに変更
    [mtk64_R_rev2-B_Cu.gbr, mtk64_R_rev2-B_Mask.gbr, mtk64_R_rev2-B_Paste.gbr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]
2022-11-26 ケースデータ修正 親指キーの向き修正
    [CE3_EC11E18244AU_Knob_x4 v1.3mf, CE3_mtk64_BP_LH_rev2 v22.3mf, CE3_mtk64_BP_RH_rev2 v22.3mf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]
2022-11-26 バックプレートアクリルカットデータ追加
    [mtk64_BP_RH.dxf]
2022-11-26 gbrファイル更新11/20発注分
2022-11-26 KeyCadバックアップファイル削除
2022-11-30 elecrow order
    [KeyBall-BOM.csv, KeyBall-BOM_eleclow.xls, KeyBall-BOM_jlc.csv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]
2022-11-30 design folder remove
    [CE3_EC11E18244AU_Knob_x4 v1.3mf, CE3_PEC12R-4025F-S0024_Knob v3.3mf, CE3_PEC12R-4222F-S0024_Knob v3.3mf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]
2023-01-21 ボール操作でレイヤー２に切り替え https://zenn.dev/takashicompany/articles/69b87160cda4b9ru
    エンコーダー誤作動対応
2023-01-21 キーマップ修正、コード整理
2023-01-21 README 自動マウスレイヤー切替機能について追記
2023-01-21 自動マウスレイヤー切替操作方法追記
2023-01-23 ファームウェア更新手順追記
2023-02-04 STLファイル
    [EC11E18244AU_Knob v1.stl, EC11E18244AU_Knob v6.stl, EC11E18244AU_Knob v8.stl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]
2023-02-04 DXFファイル
    [mtk64_BP_RH.dxf]
2023-02-04 web_updaterイメージ
2023-02-13 Update README.md
    レイヤー３トラックボール設定のコード値mtk64e 修正
2023-02-14 ビルドエラー解消 typo修正
2023-02-14 自動マウスレイヤーから元のレイヤーに戻る時間を調整可能とした
2023-02-14 ファームウエアビルド、チートシート更新
2023-02-17 エンコーダーの解像度を調整
2023-02-24 意図せずマウスレイヤーが解除されてしまうバグに対応
2023-04-13 イメージ写真追加
2023-04-13 エンコーダー写真追加
2023-04-13 Update README.md
    <img width="１０００" src="mtk/photo/mtk64e.JPG">
    <img width="500" src="mtk/photo/encoder.JPG"> <img width="500" src="mtk/photo/bord.JPG">
    <img width="500" src="mtk/photo/type-c.JPG">
2023-04-14 EC11N1524402エンコーダー用ノブ追加
    [EC11N1524402_knob_v7.stl]
2023-04-21 mtk64e回路図
2023-04-22 両側ボール スレーブ側スクロール無効化ファームウェア
2023-04-22 両側ボール片側スクロールファームウェア
2023-04-22 readme更新
2023-04-23 EXTRAKEY_ENABLE = yes に変更
2023-04-24 Update README.md
    https://usevia.app/ にvia.jsonが未対応、remapのみ対応
2023-04-29 qmk_firmware 0.16.3 で再ビルド
2023-04-29 チートシート更新
2023-05-07 PMW3360 PMW3389データシート追加
2023-05-07 PMW3360をPMW3389に単純置き換え
2023-05-09 CPI設定をPMW3389用に変更
2023-05-09 PMW3389用ファームウェア
2023-05-09 PMW3389用ファームウェア
    (cherry picked from commit a47fa8e03afe2ff82184409e51c3747fd2e19349)
2023-07-02 via用Jsonファイル追加
2023-07-05 右ロータリーエンコーダー、左ボール用、自動マウスレイヤー切替有効 ファームウェア追加
2023-07-05 右ロータリーエンコーダー、左ボール用、自動マウスレイヤー切替有効 ファームウェア再ビルド
2023-07-06 初期化処理修正
2023-07-06 自動マウスレイヤー切り替えファームウェア キーコード更新
2023-09-18 左右エンコーダー、トラックボール設定整理
    via_db削除
    エンコーダー誤作動防止修正
    hexファイル追加
    [config.h, keymap.c]
2023-09-18 PMW3360用hexファイル追加
2023-10-11 encoder_update_user 不具合修正
2023-10-11 mtk_mtk64e_PMW33xx_AutoMouseLayer_via.0.22.hex 再ビルド
2023-11-15 mtk64el readme 3Dデータ追加
    [EC11N1524402_Knob_13mm.stl, EC11N1524402_Knob_16mm.stl, mtk64el_body_RH_rev2.stl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]
2023-11-15 更新履歴追記
2023-11-26 mtk64el ケースデータ更新
    [mtk64elt_encoderCase_RH_rev2.stl, mtk64elt_promicro_case_low_RH_rev2.stl]
2023-11-26 Gateron_Upgrade_Low_Profile_switch_Hot-swap_PCB_2.0_Socket FootPrint
2024-01-04 mtk64elt_STL/rev2 ファイル更新
    [mtk64el_body_RH_rev2.stl, mtk64elt_TentLeg_LH_rev2.stl, mtk64elt_TentLeg_RH_rev2.stl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]
2024-02-10 readme更新 mtk64el rev3 ケースデータ
    [EC11N1524402_Knob_13mm.stl, EC11N1524402_Knob_16mm.stl, mtk64el_body_LH_rev2.stl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]
2024-02-10 画像サイズ修正
2024-03-03 プリント設定変更
2024-03-20 ケースデータ更新
    [mtk64el_rev3_body_LH.stl, mtk64el_rev3_body_RH.stl, mtk64el_rev3_bottomPlateTrackballSide_RH.stl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]

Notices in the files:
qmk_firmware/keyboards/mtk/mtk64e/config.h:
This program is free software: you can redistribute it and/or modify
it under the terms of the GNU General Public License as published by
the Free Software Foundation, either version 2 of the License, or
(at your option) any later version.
